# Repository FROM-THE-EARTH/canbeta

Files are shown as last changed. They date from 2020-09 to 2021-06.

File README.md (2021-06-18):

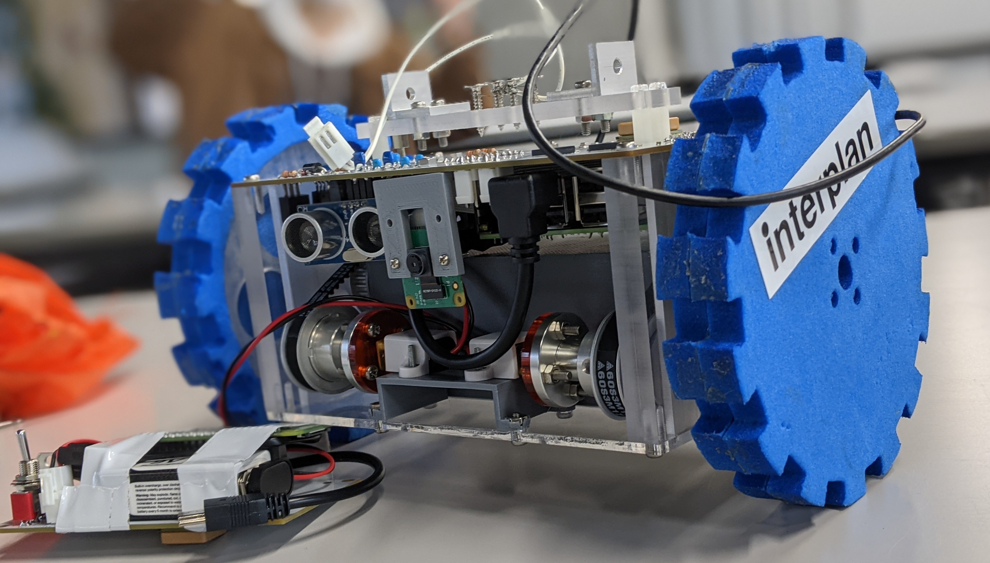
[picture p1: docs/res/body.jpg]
CanSat Beta (https://FROM-THE-EARTH.github.io/canbeta)


# canbeta

東北大学 [FTE](https://www.fte-tohoku.org/) CanSat チーム9期代のプロジェクトです．

## Dependancies

[Pipfile](./Pipfile) を参照してください．
フレームワークは [pisat](https://github.com/jjj999/pisat) を使っています．

## 開発者へ

* 必ずクローンしたら pipenv で Pipfile に沿った仮想環境を作成してください

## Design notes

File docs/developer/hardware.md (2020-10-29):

# ハードウェアとインターフェイス

## 回路図

回路図は[ドライブ](https://drive.google.com/drive/u/3/folders/1yeRXrsquoPqAf5KEmQhBFVWh2i_2MZr4)から参照可能です．
図が見づらい場合はそちらを参照してください．

### 親機

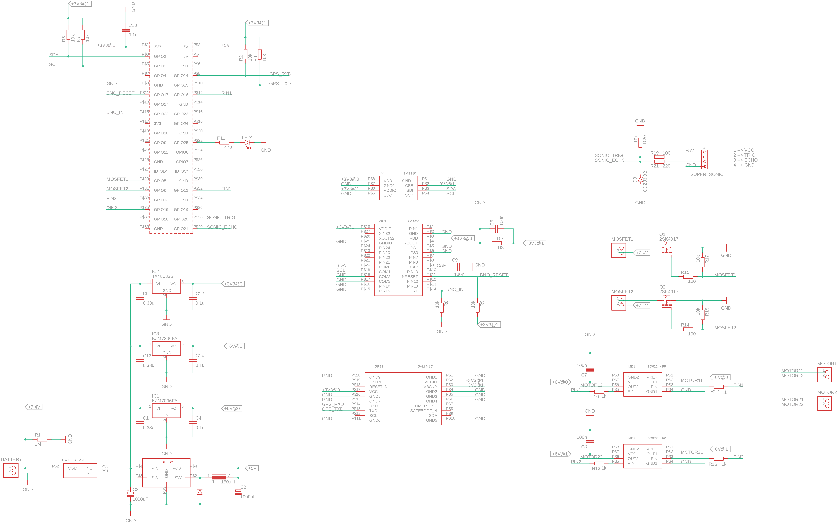
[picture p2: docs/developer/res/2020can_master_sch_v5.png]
master


### 子機

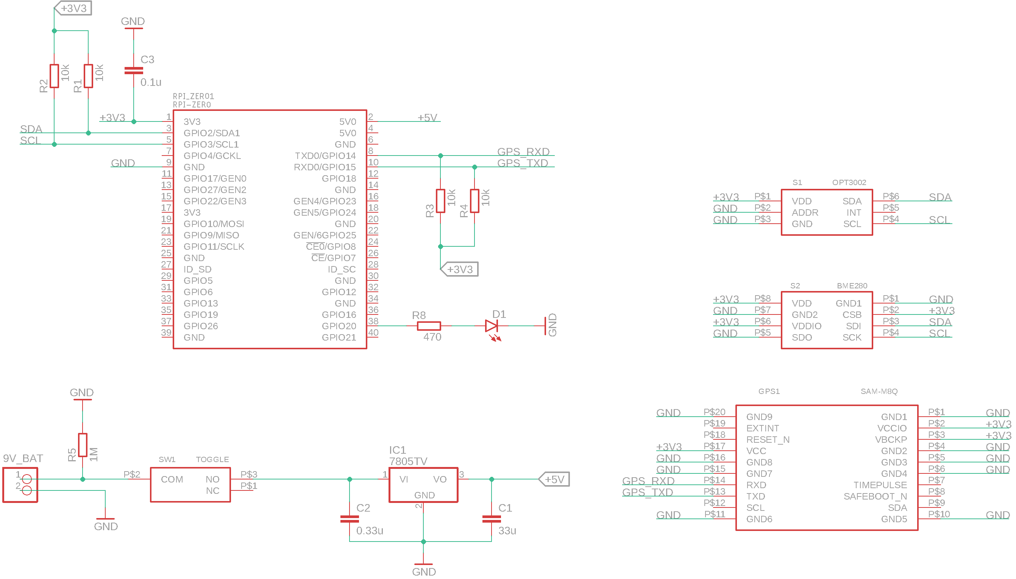
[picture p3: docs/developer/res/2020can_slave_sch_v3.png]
slave


## インターフェイス

### 親機

親機の Raspberry Pi のインターフェイスは以下のとおりです．

- I2C (BNO055, BME280)
- UART (SAM-M8Q)
- GPIO13, GPIO19, GPIO18, GPIO12 (モータドライバ)
- GPIO5, GPIO6 (電熱線用 MOSFET)
- GPIO20, GPIO21 (超音波センサ)
- GPIO17 (BNO055 リセット用)
- GPIO22 (BNO055 割り込み用)
- USB0 (IM920)

それぞれの概要については以下に示すとおりです．

#### I2C

I2C は BNO055 (9軸慣性センサ)，BME280 (気圧温湿度センサ) を利用するために用います．
I2C による信号処理のためには pisat.handler.PigpioI2CHandler を用います．
センサの利用は pisat.sensor.Bno055，pisat.sensor.Bme280 クラスを用います．
各センサの I2C アドレスは以下のとおりです．

センサ    | I2C アドレス
:--------:|:-------------:
BNO055    | 0x28
BME280    | 0x76

#### UART

UART は GPS 受信モジュールである SAM-M8Q を利用するために用います．
UART の処理には pisat.handler.PyserialSerialHandler を用います．
GPS モジュールの利用には pisat.sensor.SamM8Q クラスを用います．
使用するシリアルポートは **/dev/serial0** です．

#### GPIO13, GPIO19, GPIO18, GPIO12

これらの GPIO ピンは PWM 出力用に用います．
モータドライバは BD6222HFP です．
PWM の出力は pisat.handler.PygpioPWMHandler を用います．
2つのモータドライバは1つの二輪車として pisat.actuator.TwoWheels クラスを用いて操作します．

#### GPIO5, GPIO6

これらの GPIO ピンは MOSFET を動作させるために使用します．
pisat.handler.PigpioDigitalOutput クラスを直接用いて操作します．

MOSFET はこれらの GPIO ピンの電圧レベルを HIGH にすると動作し，電熱線に電流を流します．
つまり，テグスを焼きたいときに GPIO ピンの電圧レベルを HIGH にします．

#### GPIO20, GPIO21

これらの GPIO ピンは超音波センサを利用するために使用します．
GPIO20 は超音波センサへトリガーを送るためのデジタル出力ピンとして用います．
GPIO21 は超音波センサから返される信号を読み取るためのデジタル入力ピンとして用います．

#### GPIO17

このピンはデジタル出力として用います．
デフォルトの電圧レベルは HIGH です．
BNO055 をリセットさせる際には電圧レベルを LOW にします．

#### GPIO 22

このピンはデジタル入力として用います．
BNO055 の割り込み機能を利用する場合に用いるピンです．
割り込みが検出されると電圧レベルが HIGH になるため，これを検出することで割り込みを処理できます．

#### USB0

この USB は IM920 を利用するために使用します．
USB の使用には pisat.handler.PyserialSerialHandler を利用します．
IM920 をソケット感覚で使用したい場合は SocketTransceiver クラスでラップする必要があります．
使用するシリアルポートは **/dev/ttyUSB0** です．

### 子機

子機の Raspberry Pi のインターフェイスは以下のとおりです．

- I2C (BME280, OPT3002)
- UART (SAM-M8Q)
- USB0 (IM920)

#### I2C

I2C は BME280 (気圧温湿度センサ), OPT3002 (光センサ) を利用するために用います．
I2C による信号処理のためには pisat.handler.PigpioI2CHandler を用います．
センサの利用は pisat.sensor.Bme280, pisat.sensor.Opt3002 クラスを用います．
各センサの I2C アドレスは以下のとおりです．

センサ    | I2C アドレス
:--------:|:-------------:
BME280    | 0x76
OPT3002   | 0x68

#### UART

UART は GPS 受信モジュールである SAM-M8Q を利用するために用います．
UART の処理には pisat.handler.PyserialSerialHandler を用います．
GPS モジュールの利用には pisat.sensor.SamM8Q クラスを用います．
使用するシリアルポートは **/dev/serial0** です．

#### USB0

この USB は IM920 を利用するために使用します．
USB の使用には pisat.handler.PyserialSerialHandler を利用します．
IM920 をソケット感覚で使用したい場合は SocketTransceiver クラスでラップする必要があります．
使用するシリアルポートは **/dev/ttyUSB0** です．

## 開発の際に

開発の際にはハードウェアを利用する Node も多くあるかと思います．

まずセンサですが，**センサを明示的に利用することは避けてください**．
ただし，センサの設定を変えたい場合は別です．
そのような場合は，Node.enter コールバックで行ってください．
なぜなら，Node.judge ではセンサは常に Main スレッドに拘束されているからです．

一方，モータや通信機は特定のスレッドに拘束されていませんので，基本的には自由に使うことが出来ます．
特に Node.control 内で利用するのが良いです．

ハードウェアの部品変更があり，pisat のコンポーネントが追いついていないものがありますが，
それぞれの**基底クラス (Base の名前がついているクラス) は既に完成済み**です．
実際に使うことになる具象クラスは基底クラスのメソッドを持っているので，
具象クラスが完成していなくてもコード自体は書けます (具象クラスの実装を行うのは pisat 管理者の役目です)．

## 部品ークラス対応表

9/30 時点での部品とクラスの対応表は以下のとおりです．

| 部品名    | 具象クラス | 基底クラス                  | 具象クラスの実装状態
:----------:|:----------:|:---------------------------:|:----------------------------:
BNO055      | Bno055     | SensorBase                  | 未
BME280      | Bme280     | SensorBase                  | 済
OPT3002     | Opt3002    | SensorBase                  | 未
SAM-M8Q     | SamM8Q     | SensorBase                  | 未
*BD6222HFP  | BD62xx     | SimplePWMDCMotorDriver      | 済
IM920       | Im920      | TransceiverBase             | 済

(*注) BD62xx クラスは単体で使用せず，TwoWheels クラスを利用してください．
ただし，TwoWheels クラス生成の際に BD62xx オブジェクトが2つ必要になります．

## まとめ

ここではソフトウェア開発に必要な最低限のハードウェアの内容を説明しました．
ソフトウェアはハードウェアの抽象化の上に構築されるので，特に内部の実装に気を配る必要はありません．
ただし，抽象化されたクラスの使い方には習熟しておく必要があります．
その使い方は具象クラスの docstring などを読めばわかります．
もし，具象クラスが未実装の場合はその基底クラスを見れば大体の使い方を知ることが出来ます．

[次のドキュメント](./test.md)ではテスト方法について説明します．

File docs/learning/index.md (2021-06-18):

# 概要

ここでは後世の CanSat チームの後輩たちのための有益な情報（特に電装開発についての情報）をまとめています．ドキュメントは随時更新予定です．

## 何から始めるの？

CanSat の開発をまだ行ったことのない人にとっては，このドキュメントをどのように読み進めて良いかすらあまりわからないかもしれません．最終的に CanSat 開発を行うには，このドキュメントで述べる内容を網羅的に把握しておく必要がありますが，かといってこれらを順番に読み進めるのは退屈でつまらないことかもしれません．ここでは，読者の性質別におすすめコンテンツを紹介します．

### 完全初学者の方の場合

CanSat 開発の右も左もわからない完全初学者の方は，まず[ソフトウェア一般](software/index.md)や [Python](python/index.md) のドキュメントを読んでみるのをおすすめします．なぜなら，そもそもソフトウェアに馴染みのない状態では，実際のプログラミングや Raspberry Pi の話題にはついていけないからです．まずは，ソフトウェアの基本的な事項やプログラミング言語について学習して，ソフトウェアをもっと身近なものにすると，より発展的な議論に対する理解が進むことでしょう．

### プログラミングに自信がある方の場合

ある程度ソフトウェアやプログラミングの知識があるという方は，[ロボットプログラミング](robot/index.md)や [Raspberry Pi](raspi/index.md) などのトピックに触れてみるといいかもしれません．これらは特有のドメインを持っていて，そのドメインをよく知る人たちは（おそらく）あまり多くありません．このドキュメントはこれらの学習への良い道標になるでしょう．

### PM や AM の方の場合

PM や AM は以下のコンテンツ全般についてある程度知っておく必要がありますが，その中でも[チーム開発](team/index.md)を重点的に学習すると良いでしょう．PM や AM の役目は開発のマネージメントなので，チーム開発をどのように行えば良いかについて，他のメンバーより深く知っておく必要があります．

!!! Tip
    PM や AM が凄腕プログラマーである必要性は全くありません．PM や AM の役目はあくまでマネージメントなので，チームメンバーの責任が当分配されるように工夫するといいかもしれません．

## コンテンツ

### [ソフトウェア一般](software/index.md)

### [チーム開発](team/index.md)

### [Python](python/index.md)

### [ロボットプログラミング](robot/index.md)

### [回路設計](circuit/index.md)

### [Raspberry Pi](raspi/index.md)

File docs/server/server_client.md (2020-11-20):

# サーバーとクライアントの扱いについて

## サーバーの起動

サーバーを起動するためには，[CommandServer](../../can09/server/command_server.py) クラスを利用します．

### サーバーの初期化

*CommandServer* を初期化するためには *SocketTransceiver* オブジェクトと *Request* クラスが必要です．

*SocketTransceiver* オブジェクトは [pisat](https://github.com/jjj999/pisat/) で定義されています．
このオブジェクトは

```python
# TransceiverBase を継承したクラスのオブジェクトを作る
im920_server_handler = PyserialSerialHandler("/dev/tty/USB0")
im920_server = Im920(im920_server_handler)

# TrasnceiverBase を継承したクラスのオブジェクトをラップする
socket_transceiver_server = SocketTransceiver(im920_server)
```

のように作成します．
この SocketTransceiver オブジェクトは通信のハードウェアを定義するために必要です．

次に *Request* クラスを準備する必要があります．
これは，既に用意されているのでインポートするだけで OK です．

```python
from can09.server import Request
```

このオブジェクトはクライアントからのリクエストを処理するために必要です．
*Request* はユーティリティクラスなのでインスタンス化する必要はありません．

これらを踏まえてサーバーの初期化は

```python
from can09.server import CommandServer

server = CommandServer(socket_transceiver_server, Request)
```

で行えることが出来る．

### コマンドの登録

サーバーを初期化したら，起動する前にまずコマンドを登録する必要があります (コマンドの詳細は[こちら](./command.md))．
コマンドの登録は *append* メソッドを使って行います．
*append* は任意個のコマンドを受け付けます．

```python
# TestCommand1, TestCommand2 というコマンドがあるとします
server.append(TestCommand1, TestCommand2)
```

コマンドが比較的多い場合，

```python
commands = (TestCommand1, TestCommand2, TestCommand3, TestCommand4)
server.append(*command)
```

のように登録すると便利です．

### サーバーの起動

コマンドが登録できたらサーバーを起動できます．
サーバーは *start_serve* メソッドを利用して起動できます．
もしコマンドが1つも登録されていない場合には *RequestCommandError* を送出します．

```python
server.start_serve()
```

サーバーを起動する際はタイムアウトを設定できます．
単位は秒です．
タイムアウトは**クライアントからの1回のリクエスト受付の最大の待機時間**です．
決して，タイムアウトに設定した時間が経過すると終了するというわけではありません．

例えばタイムアウトを5秒に設定すると，5秒間リクエストがなければサーバーは終了します．
しかし，クライアントから3秒間隔でリクエストが来るような場合ではサーバーは起動し続けます．

```python
# タイムアウトを5秒に設定する場合
server.start_serve(timeout=5.)
```

## リクエストの送り方

これまでサーバー側の説明をメインに行ってきましたが，もちろんクライアント側にも所定の手順が存在します．

### サーバーへのソケットを作成する

サーバーとの通信において，クライアントを表現する特別なクラスはありません (必要ないからです)．
なので，pisat の TransceiverBase を継承したクラスのような通信機能を持つクラスならなんでも使えることになりますが，*SocketTransceiver* を利用して *CommSocket* オブジェクトを作成し通信するのが便利です．

*SocketTransceiver* のセットアップ方法はサーバーの説明で示した方法と全く同じです．

```python
from pisat.handler import PyserialSerialHandler
from pisat.comm.transceiver import Im920, SocketTransceiver

# TransceiverBase を継承したクラスのオブジェクトを作る
im920_client_handler = PyserialSerialHandler("/dev/tty/USB1")
im920_client = Im920(im920_client_handler)

# TrasnceiverBase を継承したクラスのオブジェクトをラップする
socket_transceiver_client = SocketTransceiver(im920_client)
```

次に，*CommSocket* オブジェクトを *SocketTransceiver.create_socket* メソッドを使って作成します．

```python
# アドレスの表記方法は Transceiver クラスによって異なります
# Im920 の場合はデバイスの ID のみで識別します
server_address = (3B6D,)

# 相手側のアドレスを指定してソケットを作成します
socket = socket_transceiver_client.create_socket(server_address)
```

このようにソケットを作成する利点は以下のとおりです．

- 相手側のアドレスは作成時に一回だけ指定すれば良い
- 相手が複数存在する場合にオブジェクトで区別出来る
- 他の相手とのデータの送受信の影響を受けない
- パケット量 (一度の通信でのバイト数の制限) を気にしなく良くなる

上記の利点はクライアントサーバーモデルを実装する上で重要です．
特にパケット量を気にする必要がないのは非常に強力で，多様なリクエストを可能にします．
例えば，CommSocket を用いず Im920 クラスをそのまま使った場合，リクエストが 64 byte を超過するとエラーが発生してしまいます．
つまり，リクエストは 64 byte 以下でなければならないという制限が課せられることになります．
しかし，この問題は CommSocket を利用することで回避できます．
このような理由から，クライアントが CommSocket を利用することはデファクトスタンダードであると言えます．

### ソケットでリクエストを送る

リクエストの送り方は [コマンドの説明](./command.md) で述べたレスポンスの送り方とほとんど同じです (ここではレスポンスも一種のリクエストとして実装されているからです)．
すなわち，

1. RequestForm を使ってフォームを生成
2. フォームに記入 (フォームの内容を埋める)
3. Request.make_request を使ってフォームの内容からフォーマット済みデータを作成
4. フォーマット済みデータを送信

の手順を踏みます．
最後の送信はもちろん CommSocket を利用します．

例として，以下のようなコマンドが定義されているとします ([コマンドの説明](./command.md)で使用したコマンドクラスです)．

```python
from pisat.comm.transceiver import CommSocket

from can09.server import CommandBase, ResponseBase
from can09.server import RequestForm, RequestParams, Request

class CatCommand(CommandBase):
    COMMAND = b"BB"
    LEN_ARGS = CommandParams.ARGS_ARBITARY

    @classmethod
    def exec(cls, socket: CommSocket, params: RequestParams) -> None:
        # 引数を結合する
        data_concatenated = b"".join(params.args)

        # 以下はレスポンスの作成

        # フォームを作成
        form = RequestForm()
        form.reception_num = params.reception_num
        form.command = ResponseBase
        form.args = (data_concatenated,)

        # フォームからデータを生成
        data_sending = Request.make_request(socket, form)

        # フォーマット済みデータを送信
        socket.send(data_sending)
```

このコマンドをリクエストとしてフォーマットしてサーバーに送るためには以下のようにします．

```python
import codecs

from pisat.comm.transceiver import Im920

from can09.server import CommandBase, ResponseBase
from can09.server import RequestForm, RequestParams, Request

# ソケット作成部分は省略

args = ["Hello", "World", "!!!"]
args = tuple(map(Im920.encode, args))

# RequestForm オブジェクトを作成
form = RequestForm()

# フォームに必要な内容を登録
form.reception_num = 100
form.command = CatCommand
form.args = args

# フォーマット済みデータを生成
data_sending = Request.make_request(socket.addr_yours, form)

# IM920 はASCII文字の16進数表現なので追加で変換
data_sending = codec.encode(data_sending, "hex_codec")

# データ送信
socket.send(data_sending)
```

### レスポンスを確認する

リクエストを送るとコマンドによってはサーバーはレスポンスを返します．
さきほど例として作った CatCommand もレスポンスを返すコマンドです．
レスポンスを見るためには *Request* クラスの *parse_request* メソッドを使います．
このメソッドを使用すると，リクエストが解析され *RequestParam* というクラスが返ってきます．
この *RequestParams* クラスにはレスポンスとして送られきた内容が全て含まれています．

```python
# レスポンスを解析する．CommSocket オブジェクトを渡すことで
# 勝手に必要なだけデータを受信し解析を行うので，このメソッド
# を呼び出す前に socket.recv などでデータを受信する必要はあり
# ません (というかデータが壊れるのでやらないでください)．
params = Request.parse_request(socket)
```

*RequestParams* には以下のような属性があります．

- *reception_num* (リクエストを送る際に設定した数字)
- *command* (レスポンスなので **FF** で固定)
- *address* (サーバーのアドレス)
- *args* (レスポンス内容)

それぞれ[フォーマットの説明](./format.md)で述べたパラメータに対応しています．
最も重要な属性は *RequestParams.args*  という属性です．
この属性にはレスポンスの内容がタプルとして格納されています．
例えば上の例だと，CatCommand というコマンドはクライアントから受け取った引数を結合し，レスポンスとして返すコマンドであったので，

```python
# 内容は bytes で格納されているのでデコードして str にしておく
args = list(map(Im920.decode, params.args))

print(args)
# [HelloWorld!!!]
```

のように返ってくるはずです．
このようにしてサーバーがリクエストに対して返したレスポンスを確認することが出来ます．

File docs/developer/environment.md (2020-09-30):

# 環境構築

## Python

まずは PC 内で開発を行うための環境構築を行ってください．
開発で使用するのは **Python 3.7** です．
もし，Python 3.7 以外のバージョンしかインストールされていない場合は
pyenv などを利用し Python 3.7 を使用できる環境を整えてください．
別のバージョンが存在したとしても，特に削除する必要はありません．

### pyenv 

以下のサイトを参考に pyenv をインストールし，Python のバージョン管理を出来るようにしてください．

- [Windows](https://obataka.com/create-windows-python-virtualenv/)
- [Mac](https://qiita.com/koooooo/items/b21d87ffe2b56d0c589b)
- [Linux](https://qiita.com/neruoneru/items/1107bcdca7fa43de673d)

### pipenv

pipenv は Python の仮想環境を構築し，外部ライブラリの依存関係をその中に整理するために使用するツールです．
インストールは

```
$ pip install pipenv
```

で出来ます ($ はコマンドを示すための単なる記号で入力しなくていいです)．
pipenv がインストール出来たら，clone してある fte-can09 リポジトリのルート(ディレクトリの最上部) で

```
$ pipenv install
```

をすると仮想環境を構築し，fte-can09/Pipenv に定義してある外部ライブラリをインストール出来ます．
**Pipfile** はそのプロジェクトの環境の全てが記載されているファイルです．
Pipfile さえあれば，pipenv を用いていつでも容易に環境構築が可能です．

その他の pipenv の使用方法は[こちら](https://qiita.com/y-tsutsu/items/54c10e0b2c6b565c887a)を参照してください．

### VS Code の設定

エディタは VS Code を利用することを推奨しています．
拡張機能についての制限は特に行っていません．

VS Code では構文解析を行う Python インタープリタを指定することが出来ます．
今回は pipenv で仮想環境を構築したので，その環境でのインタープリタを使用します．
まず，Python スクリプトを開いている状態で，VS Code の画面下の青いバーの左側にある Python... という項目をクリックします．
その後，画面上部中央に利用可能な Python インタプリタがリストされると思いますが，
そこで fte-can09 の名前を含むものを選択します．
すると，編集している Python スクリプトがその仮想環境内で使用している外部ライブラリなどをもとに解析されるので，
インポートエラーのような表示が出なくなります．

### 環境構築における注意点

- pipenv で勝手に他の外部ライブラリをインストールしないでください
- 外部ライブラリが必要になるようであれば，MTG で相談してください
- わからないことがあったら積極的に聞いてください

## Raspberry Pi

### SD

Raspberry Pi 用の SD カードの作成は [Raspberry Pi Imager](https://www.raspberrypi.org/downloads/) を使用すると楽です．
OS は Raspberry Pi OS を選択してください．

### Python

Raspberry Pi における Python の環境構築は PC での環境構築方法と同一です．
pipenv は環境構築のために使うので必ずインストールしておいてください．
VS Code は今のところ公式でサポートされていないのでインストールしなくても大丈夫です．

Raspberry Pi をインストールしたての状態では，ターミナル上で

```
$ python
```

と打つと Python 2系が起動されます．Python 3系を起動するためには

```
$ python3
```

と打つ必要があります．
面倒な場合はエイリアスを作成する方法があります．

### Git

Git はデフォルトでインストールされていないかもしれないのでインストールしておきましょう．
ターミナルで，

```
$ sudo apt install git
```

と打てばインストール出来ます．
ユーザー名と E-mail アドレスの設定なども行っておきましょう．

Git のセットアップが出来たら，このリポジトリをクローンしてください．

```
$ git clone https://github.com/jjj999/fte-can09.git
```

クローンし終わったらそのリポジトリのルートに移動し，Python の環境構築を行うために

```
$ pipenv install
```

をします．
これで PC と Raspberry Pi の Python に関する環境が同期されます．

## まとめ

今回のプロジェクトで環境構築が必要なデバイスは

- PC
- Raspberry Pi

の2つです．
また，それぞれの環境を出来るだけ近いものにするために **pipenv** を用います．
環境構築は面倒ですが，一度理解してしまえば単純作業です．

環境構築のためのツールとして，今回のプロジェクトでは

- pyenv
- pipenv
- Git

を利用します．
重要な点は Pipfile さえあれば pipenv で Python の環境構築がほぼ終わるということです．

[次のドキュメント](./development.md)では開発の流れについて説明します．

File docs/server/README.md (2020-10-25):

# サーバー機能について

## 概要

サーバー機能は文字通り機体にサーバーとしての振る舞いをさせるための機能です．
サーバー機能に関するコードは [can09/server/](../../can09/server/) にあります．

そもそもサーバーとは，コンピュータネットワークモデルの1つである[クライアントサーバーモデル](https://ja.wikipedia.org/wiki/%E3%82%AF%E3%83%A9%E3%82%A4%E3%82%A2%E3%83%B3%E3%83%88%E3%82%B5%E3%83%BC%E3%83%90%E3%83%A2%E3%83%87%E3%83%AB)におけるサーバーのことです．
クライアントサーバーモデルにはクライアントとサーバーという2つの登場人物が出てきて，クライアントがサーバーに何らかの処理を**リクエスト**し，サーバーがそのリクエストに対して**レスポンス**を返すという方式をとります．
つまり，クライアントとサーバーには明確な主従関係があることになります．

今回のミッションでクライアントサーバーモデルを採用する理由は，親機は基本的にアクティブであるのに対し，子機はアクチュエータを持たず，ミッション中の単体の役割が曖昧である点にあります．
そこで，**子機をサーバー化**してしまい，親機をクライアントとすることで，子機のミッション中における役割を明確化することにしました．

本ミッションではクライアントは親機および管制局なので，クライアントサーバーモデルを採用する大きな恩恵は受けられませんが，このモデルは複数の機体をいっぺんに走査させる場合には大きな価値を持ちます．
つまり，クライアントが惑星探査を行いながら，データの整合性やミッションの進捗などをサーバーが管理するわけです．
残念ながら今回のミッションではそのような大規模なことは行えませんが，今後の開発の指針となるような試みであるとは言えるでしょう．

## フォーマット

クライアントがサーバーにリクエストを送るにも，サーバーがクライアントにレスポンスを送るにも，どちらもある決まったデータのフォーマットを必要とします．
もし所定のフォーマットでデータが送られてこなければ，コンピュータはデータを認識することが困難になるためです．

フォーマットは[こちら](./format.md)で定義されています．
フォーマットの詳細を把握する必要はありませんが，通信関連の処理を行う場合にはざっくりと把握しておくと良いでしょう．

## コマンド

リクエストの中身は主に**コマンド**とその**引数**で出来ています．
これは，ターミナルで打つコマンドの内容を通信でやり取りしているというイメージです．

コマンドは [CommandBase](../../can09/server/command_base.py) を継承するクラスで表現されます．
コマンドクラスの詳細については[こちら](./command.md)を参照してください．

## サーバーとクライアント

フォーマットやコマンドはただの情報を表す概念に過ぎません．
実際にフォーマットやコマンドを使って通信を行うのはサーバーとクライアントです．

サーバーは [CommandServer](../../can09/server/command_server.py) を利用します．
このクラスはサーバーを起動するとクライアントからのリクエストを受け付け，リクエストが来るとその内容 (主にコマンドと引数) を解析し，その内容に基づいて処理を行い，必要があればクライアントにレスポンスを返します．

クライアントにはクライアント用の特別なクラスは用意されていませんが，pisat.comm.transceiver.CommSocket を利用すると便利です．
このクラスは自分のアドレスと相手のアドレスをつなぎ，まるでその間だけの通信であるかのように偽装します．
つまりクライアントは CommSocket をサーバーのアドレスを指定して生成することで，サーバーとのコネクションを獲得するわけです．

サーバーとクライアントの詳細については[こちら](./server_client.md)を参照してください．

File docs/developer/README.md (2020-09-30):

# 開発ドキュメント

本プロジェクトの開発者用ドキュメントです．

## 目次

1. [環境構築](./environment.md)
2. [開発の流れ](./development.md)
3. [ハードウェアとインターフェイス](./hardware.md)
4. [テストと依存関係の解決](./test.md)

## 参考文献

### Python 一般

- [チュートリアル](https://docs.python.org/ja/3/tutorial/index.html)
- [標準ライブラリ](https://docs.python.org/ja/3/library/index.html#library-index)
- [言語リファレンス](https://docs.python.org/ja/3/reference/index.html)

### よく使うと思われる Python ライブラリ

- [組み込み関数](https://docs.python.org/ja/3.6/library/functions.html)
- [組み込み型](https://docs.python.org/ja/3.6/library/stdtypes.html)
- [コンテナデータ型 collections](https://docs.python.org/ja/3.6/library/collections.html)
- [列挙型 enum](https://docs.python.org/ja/3.6/library/enum.html)
- [数学関数 math](https://docs.python.org/ja/3.6/library/math.html)
- [csv](https://docs.python.org/ja/3.6/library/csv.html)
- [json](https://docs.python.org/ja/3.6/library/json.html)
- [スレッド threading](https://docs.python.org/ja/3.6/library/threading.html)
- [並列タスク実行 concurrent.futures](https://docs.python.org/ja/3.6/library/concurrent.futures.html)
- [テストフレームワーク](https://docs.python.org/ja/3.6/library/unittest.html)

### よく使うと思われる Python 外部ライブラリ

- [pigpio](http://abyz.me.uk/rpi/pigpio/python.html)
- [picamera](https://picamera.readthedocs.io/en/release-1.13/)
- [Numpy](https://numpy.org/doc/stable/)
- [Matplotlib](https://matplotlib.org/contents.html)
- [OpenCV](https://docs.opencv.org/master/d6/d00/tutorial_py_root.html)

### pyenv

- [Windows](https://obataka.com/create-windows-python-virtualenv/)
- [Mac](https://qiita.com/koooooo/items/b21d87ffe2b56d0c589b)
- [Linux](https://qiita.com/neruoneru/items/1107bcdca7fa43de673d)

### pipenv

- [入門](https://qiita.com/y-tsutsu/items/54c10e0b2c6b565c887a)
- [基礎](https://pipenv-ja.readthedocs.io/ja/translate-ja/basics.html)
- [応用](https://pipenv-ja.readthedocs.io/ja/translate-ja/advanced.html)

### Git

- [Git book](https://git-scm.com/book/ja/v2/)
- [基礎](https://tracpath.com/bootcamp/learning_git_firststep.html)

### Markdown

- [チートシート](https://gist.github.com/mignonstyle/083c9e1651d7734f84c99b8cf49d57fa)

### Raspberry Pi セットアップ

- [Raspberry Pi Imager](https://www.raspberrypi.org/downloads/)

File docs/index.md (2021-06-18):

CanSat Beta (https://FROM-THE-EARTH.github.io/canbeta)

# canbeta

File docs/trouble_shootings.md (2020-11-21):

# トラブルシューティング

## BNO055 の出力がずっと0になる

動作モードが config モードのままかもしれません．

```python
bno055.change_operation_mode(Bno055.OperationMode.NDOF)
```

を実行してみてください．

## シリアル通信が出来ない

デバイスファイルを読み書きする権限が付与されていない可能性があります．以下のコマンドを実行してみてください．

```
$ sudo chmod 777 (デバイス名)
```

## SAM-M8Q のデータが取れない

以下のコマンドを打ってみてください．

```
$ stty -F /dev/(デバイス名) -echo
```

デバイス名は基本は serial0 です．

## IM920 が動作しない (1)

ボーレートが合っていない可能性があります．IM920 のボーレートは19200Hzです．handler を19200Hzのボーレートで初期化して使用してください．

```python
from pisat.handler import PyserialSerialHandler
from pisat.comm.transceiver import Im920

handler = PyserialSerialHandler("/dev/ttyUSB0", boadrate=19200)
im920 = Im920(handler)
```

## IM920 が動作しない (2)

ペアリングが行われていない可能性があります．IM920 にはIDがあり，裏側に書いてある6桁の数字がIDです．相手側のIDを登録しておかないと受信を行うことが出来ません．

6桁の数字のIDの登録方法には2通りあります．1つ目の方法は数字を16進数に直して登録する方法です．

```python
# ID: 007378
# -> 16進数: 1CD2
im920.add_rec_id("1CD2")
```

2つ目の方法は6桁の数字を直接渡し，is_hex 引数を True に設定する方法です．この方法が計算しなくても出来るので簡単です．

```python
# ID: 007378
im920.add_rec_id("007378", is_hex=True)
```

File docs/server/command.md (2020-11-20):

# コマンドについて

## コマンドの定義方法

この通信におけるコマンドは通常の PC のターミナルで行うコマンドとほとんど同じ構造をしています．
つまり，コマンド名があり引数があり，その情報をもとに処理を実行します．
ただし以下の点が異なります．

- オプション引数はなく位置引数のみを持ちます
- 結果もコマンド (コマンド名はFF) として返ってくる
- コマンドは CommandBase のサブクラスとして定義される

特にコマンドの定義という点で上の3つの項目のうち最後の項目が重要になります．

コマンドの基礎となる CommandBase は非常に軽量なクラスです．
ユーザーが実質的に定義すべき項目は3つだけです:

```python
from enum import Enum, auto
from typing import Any

from pisat.comm.transceiver import CommSocket

from can09.server.request import RequestParams

class CommandParams(Enum):
    ARGS_NOTHING = auto()
    ARGS_ARBITARY = auto()

class CommandBase:
    
    COMMAND = b""
    LEN_ARGS = CommandParams.ARGS_NOTHING
    
    @classmethod
    def exec(cls, socket: CommSocket, params: RequestParams) -> Any:
        pass

class ResponseBase(CommandBase):
    
    COMMAND = b"FF"

```

*COMMAND* はコマンド名で bytes 型です．
[フォーマットの説明](./format.md)でも述べたようにコマンド名はアルファベット2文字です．

*LEN_ARGS* はコマンドの引数の数です．
特別な引数の数として CommandParams の属性を使うことも出来ますが，使わなくても OK です．

*exec* はサーバーが *COMMAND* と同じコマンド名を持つリクエストを受けた場合に呼び出されるメソッドです．
つまり，コマンドの実行は具体的にこのメソッドで行われます．
引数には *CommSocket* と *RequestParams* が渡されます．
*CommSocket* は pisat で定義されているもので，自分のアドレスと相手のアドレスをつなぎ，いかにも 2 つの端末間で通信がなされているかのように見せかけることが出来るオブジェクトです．
コマンドは *CommSocket* を使ってレスポンスを返すことが出来ます．
*RequestParams* は[フォーマットの説明](./format.md)で述べられたフォーマットの各パラメータが格納されたクラスです．
このクラスからリクエストの内容について (例えばコマンドの引数) 知ることが出来ます．

上のコードスニペットからわかるように，CommandBase にはインスタンス変数やインスタンスメソッドは一切ありません．

例として，引数を結合してクライアントにレスポンスを返すコマンドを作ってみます．

```python
from pisat.comm.transceiver import CommSocket

from can09.server import CommandBase, ResponseBase
from can09.server import RequestForm, RequestParam, Request

class CatCommand(CommandBase):
    COMMAND = b"BB"
    LEN_ARGS = CommandParams.ARGS_ARBITARY

    @classmethod
    def exec(cls, socket: CommSocket, params: RequestParams) -> None:
        # 引数を結合する
        data_concatenated = b"".join(params.args)

        # フォームを作成
        form = RequestForm()
        form.reception_num = params.reception_num
        form.command = ResponseBase.COMMAND
        form.args = (data_concatenated,)

        # フォームからデータを生成
        data_sending = Request.make_request(socket, form)

        # フォーマット済みデータを送信
        socket.send(data_sending)
```

上の例のように，レスポンスを返す手順は

1. RequestForm を使ってフォームを生成
2. フォームに記入 (フォームの内容を埋める)
3. Request.make_request を使ってフォームの内容からフォーマット済みデータを作成
4. フォーマット済みデータを送信

の流れになります．
上記の例では引数を結合するという意味のない処理をしていましたが，これを他の処理に変えることでコマンドをいくらでも多様にすることが出来ます．

## コマンドの登録

定義したコマンドはサーバーに追加してあげなければ動作しません．
サーバークラスとしては CommandServer を用いる必要があり，

```python
command_server.append(CatCommand)
```

のように，append メソッドを用いてコマンドを**クラスのまま追加**しなければなりません．

## コマンドの種類

現時点で用意されているコマンドを以下に列挙します．
アルファベット2文字はコマンド名です．

### レスポンスを返す (FF)

### プログラムを終了させる

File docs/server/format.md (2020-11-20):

# フォーマットについて

## 概要

本ミッションでは，子機は基本的にサーバーのように動作します．
もちろんネットワークはインターネットのようなものではなく IM920 による通信網であり，クライアントは親機または管制局です．

子機には IM920 を使って様々なコマンドを送れるようにします．
子機は受け取ったコマンドに応じて処理を行い，コマンドによってはレスポンスを返すことが出来ます．
一方，親機はミッション中に子機にコマンドを送り，そのレスポンスをもらいながらミッションを効果的に進めることが出来ます．

コマンドは単に送っただけでは意味がありません．
送ったコマンドは受信側で正しく解釈される必要があります．
そのためには，送信情報がコマンドを含む一定フォーマットに則っていなければなりません．
以下では，そのフォーマットを定義します．

## リクエストのフォーマット

基本的なリクエストのフォーマットは

```
$(受付番号)(コマンド名)(アドレス)$(各引数の byte 数)$(引数1)(引数2)...
```

とします．
メインのセパレータとしては **$** を使用します．

受付番号およびコマンド名は固定長なので，($ も含む) 先頭の4 byte をヘッド (head) と呼ぶことにします．

### 受付番号 (固定長 1 byte)

受付番号は1 byte (8 bit) からなります．
受付番号はクライアント側が設定できる任意の番号です．
サーバーはクライアントからリクエストを受け，その処理を実行し，レスポンスにクライアントから受け取った受付番号をそのまま添付して返します．
そして，それを受け取ったクライアントはその受付番号からどのリクエストに対するレスポンスかを判断することが出来ます．

レスポンスの速い通常のサーバーに受付番号などというものはいりませんが，子機はサーバーとしての性能は優れていないため，レイテンシの問題に対処するために受付番号を導入しました．

### コマンド名 (固定長 2 byte)

コマンド名は英数字2文字とします．
つまり，使える文字は 0 ~ 9, a ~ z, A ~ Z であり，3844通りのコマンドを設定できます．

### アドレス (任意長)

アドレスは pisat.comm.transceiver.TransceiverBase を継承したオブジェクトの送信側のアドレスです．
Transceiver オブジェクトのアドレスは一般にタプルで表現されますが，(arg1, arg2, ..., argN) で表現されるアドレスは

```
arg1:arg2:...:argN
```

とセミコロンで区切って表現します．

### 各引数の byte 数 (任意長)

byte 数は16進数で表現します．
その長さに制限はありません．
複数の引数がある場合，

```
(引数1の byte 数):(引数2の byte 数):...:(引数Nの byte 数)
```

と表現します．

これは任意のバイトを含む引数を処理するために必要な情報です．

### 引数 (任意長)

引数には特に制限はありません．
一般に引数は複数存在しますが，各引数はセパレータなしにそのまま結合されます．

## レスポンスのフォーマット

レスポンスのフォーマットはリクエストとほぼ同じです．
ただし以下の点が異なります．

- コマンドが **FF** で固定
- 引数の代わりに結果が返ってくる

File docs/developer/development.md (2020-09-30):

# 開発の流れ

## Git

開発には Git を利用します．
知識としては [Git book](https://git-scm.com/book/ja/v2/) の2, 3章を理解しておけば十分です．
忘れたら再度確認しましょう．

## 基本的な流れ

各自でブランチを作成してそのブランチ上で開発を行ってください．
開発は自分の担当の Node を最優先に行ってください (出来る限りコンフリクトは起こしたくないです)．

開発がある程度進んだら Github の Issues でマージ要求を発行するか，プルリクエストを発行してください．
適切だと判断されれば，ブランチは master にマージされます．
マージされたブランチは削除してしまって構いません．
新たにタスクが発生したら，最新の master から再度ブランチを作成してください．

## Slack との連携

リモートリポジトリ (Github上のリポジトリ) が更新されると，Slack に自動アナウンスされるように設定されています．
つまり，Push や Issues などの操作を行うと Slack に通知が来ます．
誰がやっても通知が来るので，更新を行ったら他のメンバーに知らせるために push するようにしましょう．

## その他

### 依存ライブラリの更新

以下のコマンドで，現在依存している外部ライブラリの内容を更新できます．

```
$ pipenv update
```

### 注意点

作成したブランチで master ブランチをマージすることはやめてください．

## まとめ

今回のプロジェクトでは Git を利用して

1. 各自でブランチを持つ
2. ブランチの開発がある程度終わったら master にマージ
3. 再度ブランチを作成

の繰り返しで開発を進めていきます．
更新記録は Slack を通して他のメンバーに通知されます．
他のメンバーの更新記録は時間があるときにチェックしておくと良いでしょう．

[次のドキュメント](./hardware.md) ではハードウェアの話をします．
主にピンアサインなどの確認を行います．

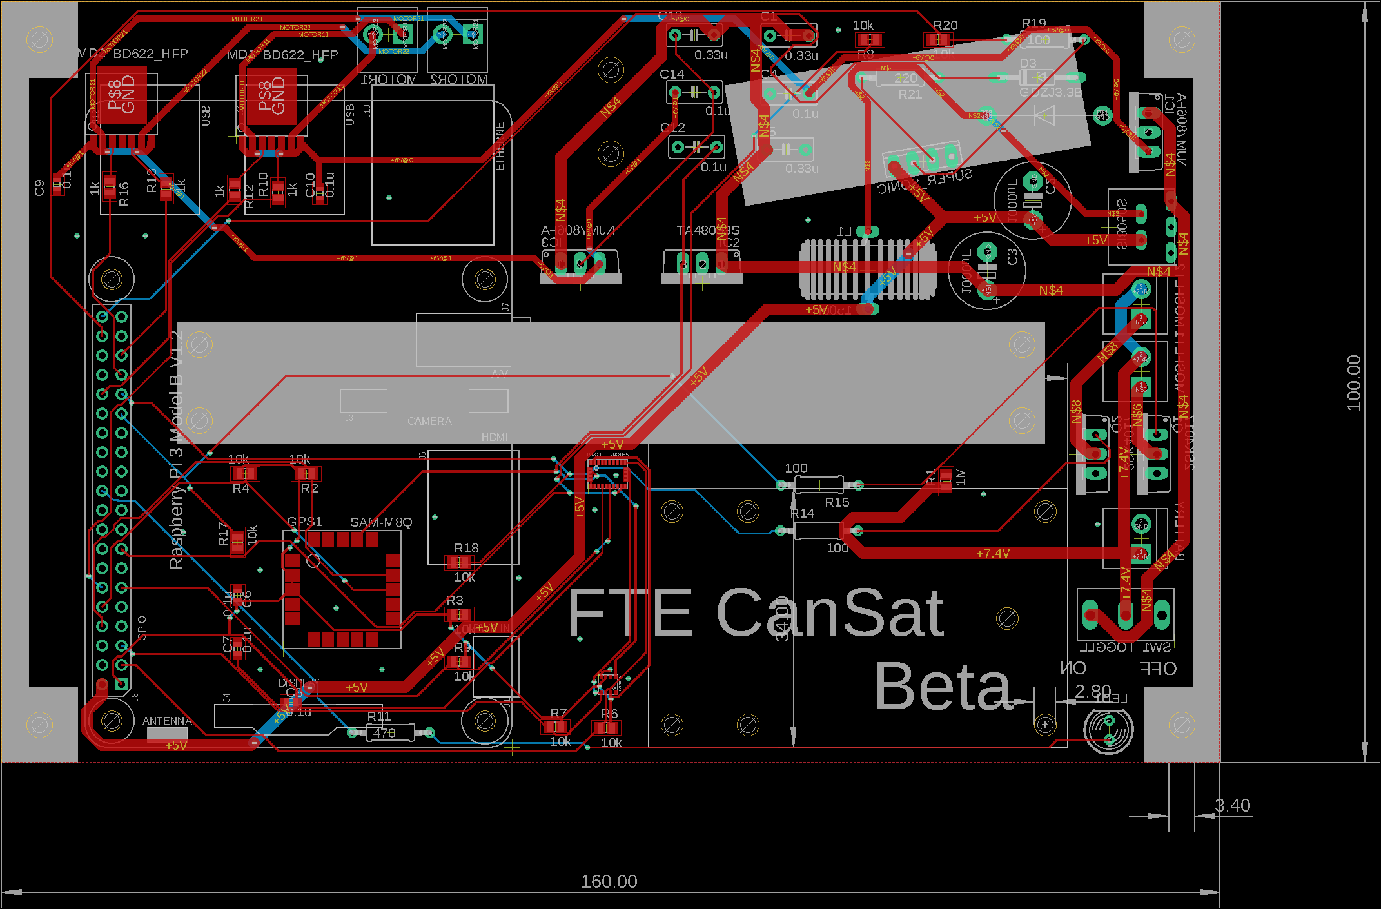
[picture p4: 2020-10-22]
circuits/images/parent_brd.png

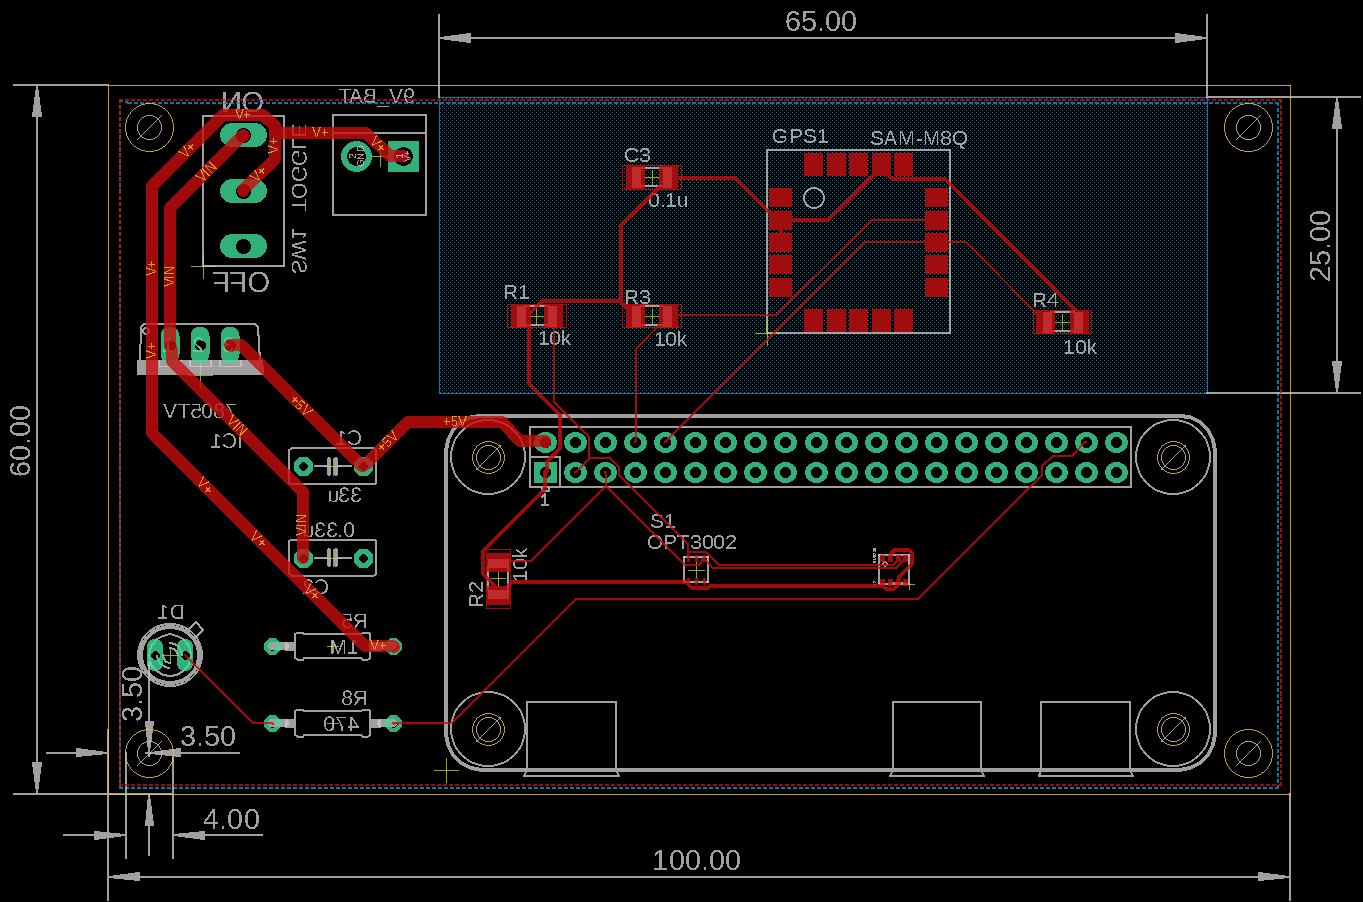
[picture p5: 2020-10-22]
circuits/images/child_brd.png

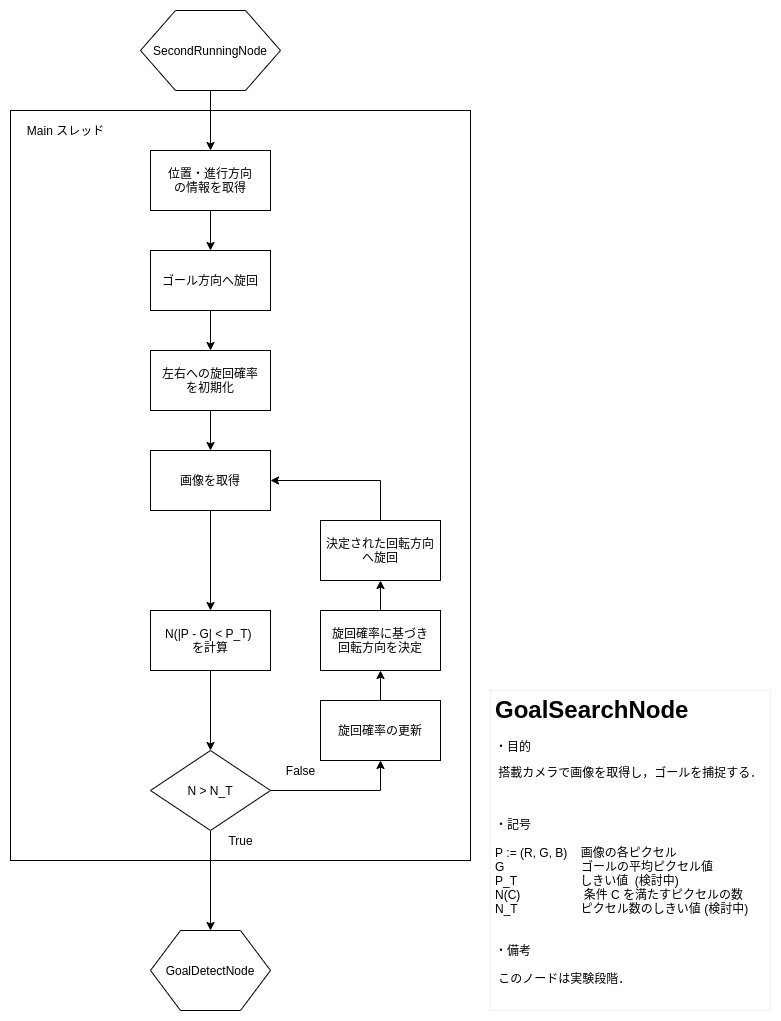
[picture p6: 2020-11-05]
docs/nodes/parent/img/goal_search_node.png

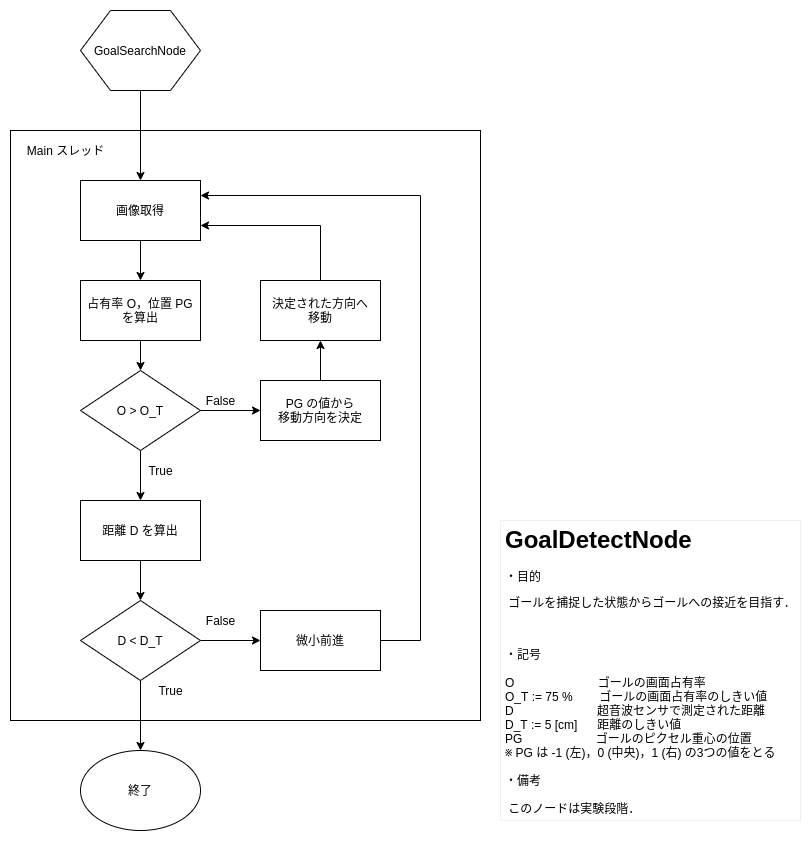
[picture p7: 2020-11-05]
docs/nodes/parent/img/goal_detect_node.png

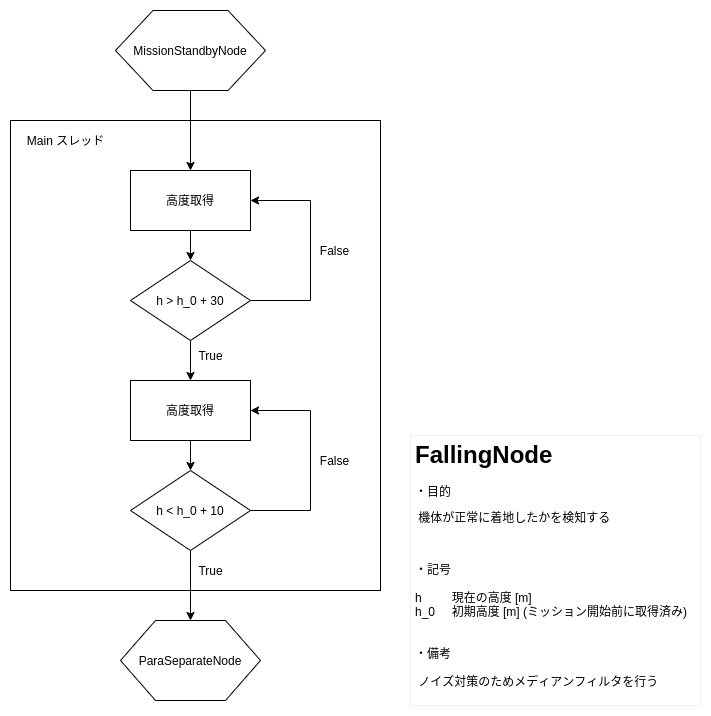
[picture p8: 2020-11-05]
docs/nodes/parent/img/falling_node.png

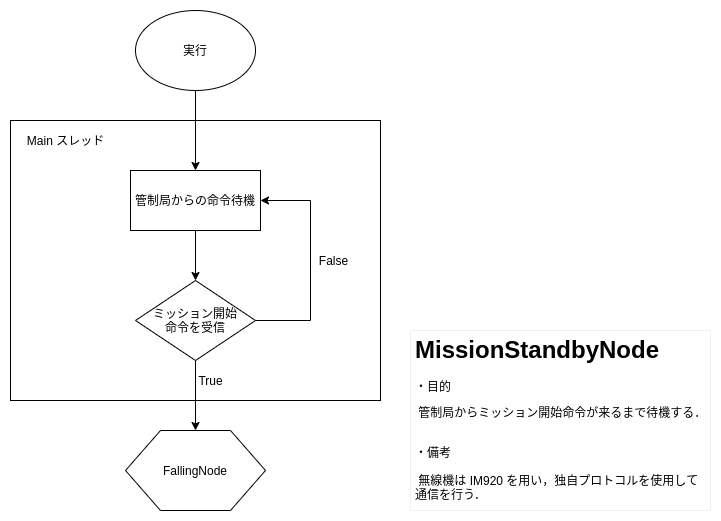
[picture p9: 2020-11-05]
docs/nodes/parent/img/mission_standby_node.png

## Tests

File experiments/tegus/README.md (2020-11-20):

# テグス熱融解試験

## 目的

パラシュートおよび子機の固定にテグスを利用し，その分離を電熱線を熱することで行う．
ここではミッションで使用するための電熱線に電圧を印加する時間を求めることを目的とする．

## 方法

電熱線に約 7.4V の電圧を印加し，テグスが融解する時間を計測する．
可能であれば複数回行う．

## 結果

テンションがかかった状態でテグスが切れるまで約 1 ~ 2 秒程度要した．

## 考察

本試験の結果から電熱線へ10秒ほど電圧を印加すればテグスは十分切れると考えられる．

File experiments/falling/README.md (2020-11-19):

# 落下検知・パラシュート分離テスト

## 目的
NSE に参加するのに伴い，参加団体には審査書の作成が求められる．
これは投下実験に参加する機体がレギュレーションに沿っているかの確認，また試験を完了できる機体であるかを事前に確認するE2E試験に分かれている．
今回は機体を用いてE2E試験を行い，またそのデータを得ることを目的とする．

## 概要

このテストでは主に MissionStandbyNode ~ ParaSeparateNode までのコンテクストについてテストする．
このテストは E2E 試験の前半部分を兼ねており，

- 管制局からのミッション開始命令をちゃんと受け取れるか
- パラシュートが適切に開くか
- パラシュート展開時の荷重がいくらか
- 着地の荷重がいくらか
- 機体が着地衝撃に対して十分な耐性があるか
- 落下時の機体の終端速度がいくらか
- パラシュート分離が適切に行われるか
- コンテクストが適切に進行するか

という点を基準に評価する．

## 方法

まず落下する地上の高度と機体を投下する地点の高度を observe_altitude.py を実行して調べ，それを記録しておく．
次に，記録した2つの高度から適切なしきい値を決定し，exp_falling.py 内で FallingNode のしきい値を決定したしきい値に上書きする．
その後，exp_falling.py を実行し，機体を投下地点に持っていき数秒間待機してから投下する．
投下後，機体を回収しデータを解析する．

### 荷重の解析

### 終端速度の解析

## 結果

- 実施日時 : 2020/11/xx
- 実施場所 : 
- 設定値
    * $h = 10$ [m]

### 開傘衝撃

### 着地衝撃

### 終端速度

## 考察

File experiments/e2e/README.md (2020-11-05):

# E2Eテスト

## 目的

作成したアプリケーションのミッション遂行能力を確かめる．

## テスト方法

### 概要

テストはコンテクストを次の2つに分けて行う．

1. MissionStandbyNode ~ ParaSeparateNode (C1)
2. FirstRunningNode ~ GoalDetectNode (C2)

2つのテストはその一部始終を動画で記録する．

### C1

C1 は[落下検知・パラシュート分離テスト](../falling/)で行った結果を利用する．

### C2

C2 は走行に関わるコンテクストである．
このテストで主に評価する部分は次の2つ:

1. 子機を定めた座標の半径$x$[m]以内に分離できるか
2. ゴール (三角コーン) へ向けて接近できているか

## 結果

### 第1実験

- 実施日時 : 2020/11/xx
- 実施場所 : 
- 設定値
    * $x = 1$
    * 子機放出座標 (latitude, longitude)
    * ゴール座標 (latitude, longitude)

## 考察

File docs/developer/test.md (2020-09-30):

# テストと依存関係の解決

## テストの概要

### テストスクリプト

テストスクリプト (テスト用の Python ファイル) は fte-can09/test/ ディレクトリ内に置いてください．
そして必ず **test_xxxxxxx.py** という命名規則でファイル名を作成してください．
xxxxxx の部分はテストするクラス名やファイル名にするとわかりやすいです．

テストスクリプトはテストしたい内容を自由に記述してください．
本来は [unittest](https://docs.python.org/ja/3.6/library/unittest.html) というテストフレームワークを
使用するべきですが，習得コストがかかるので現在は検討中です．

### 環境

PC 環境で出来るテストのほとんどが**論理テスト**です．
つまり，論理的に上手くいくかどうかのテストしか行うことが出来ません．
それもセンサやモータなどの外部機器を一切使わずにです．
ただし，PC に接続可能な機器については実機テストを一部行うことが出来ます．

基板は現在発注手続きを進めていますが，早ければ10月の中旬，遅ければ10月末あたりに完成する予定です．
つまり，11月に実機テストラッシュを行うことになるため，10月中は論理テストのみの実行で開発を進めてください．

実機がないことへの対応として，Precursor の実機を使用してみようと考えています．

## 依存関係の解決

テストスクリプトを書く際に，import エラーにハマる可能性があります．
import エラーが発生する原因は，can09 パッケージが仮想環境における Python インタプリタの参照先ディレクトリ内
に含まれていないからです．
Python インタプリタの参照先リストは

```python
import sys

print(sys.path)
```

とすると参照出来ます．
ちなみに sys.path は参照先ディレクトリのリストです．

この問題を解決するには2つの方法があります．

1. 参照ディレクトリ内に can09 のコピーを人為的に加える
2. sys.path に can09 の親ディレクトリを append する

### 参照ディレクトリ内に can09 のコピーを人為的に加える

この方法をとるためには fte-can09/local.py というファイルを使います．
Windows の場合と Mac，Linux の場合で方法が異なります．

この方法は仮想環境内に can09 を取り込ませるので，VS Code の構文解析もでき非常に便利です．
ただし，can09 が更新される度にコピーを実行する必要があります．
なぜなら，コピーした内容はその当時の内容のままだからです．

#### Windows の場合

リポジトリのルート (fte-can09 上) で **local.py** ファイルを実行します．

```
$ python local.py
```

すると，仮想環境内の参照先ディレクトリにそのときの can09 パッケージのコピーが追加されます．

#### Mac, Linux の場合

この場合，ひと手間加える必要があります．
まず，**local.py をコピー**します．
名前は **_local.py** にしておいてください (.gitignore に登録済みなので)．

```
$ cp local.py _local.py
```

そして，_local.py の印がある場所に変更を加えます．
変更する変数は **name_env** です．
これは仮想環境の名前で **fte-can09-xxxxxxxxxxxx** という名前です．
仮想環境の名前は

```
$ ls ~/.local/share/virtualenvs/
```

とすると見つけることが出来ます．
仮想環境の名前を見つけたらコピーし，*name_env* 変数に設定します．

```python
...

if __name__ == "__main__":
    name_pkg = "can09"
    name_env = "fte-can09-xxxxxxx"             # TODO add env name if in Mac or Linux
    version_python = "3.7"

    main(name_pkg, name_env)
```

そして _local.py を保存し実行します．

```
$ python _local.py
```

すると，仮想環境内の参照先ディレクトリにそのときの can09 パッケージのコピーが追加されます．

### sys.path に can09 の親ディレクトリを append する

この方法は Python 実行時に can09 をインポート出来るように設定する方法です．
can09 の親ディレクトリである fte-can09 を sys.path に append すればOKです．

```python
import sys
import os

# can09 をインポートする前に append
sys.append(os.path.abspath(".."))     # fte-can09/test にいる場合
import can09
```

この方法を利用すると特別になにかしなくても最新の can09 をインポート出来ます．
したがって上のようなコードを覚えれば便利だと思われるかもしれませんが，
次のようないくつかの欠点もあります．

- fte-can09 の場所がメンバー全員一緒とは限らない
- ファイルを書く度に必要
- VS Code による can09 パッケージの構文解析が行われない

特に1番目と3番目が開発において致命的です．
したがって，can09 のインポートエラーを解決するためには，基本的に **local.py を実行する方法** を利用してください．

## Node.judge のシミュレート

csv ファイルを用いた Node.judge のシミュレートは pisat.test.core.util 内の **simulate_judge_from** 関数を使うと便利です．
ただし制限があり，**別途 Node.judge に相当する関数を定義** する必要があります．
例えば，

```python
import pisat.config.dname as dname
from pisat.core.nav import Node

class TestNode(Node):

    def judge(self, data):
        altitude = data[dname.ALTITUDE_SEALEVEL]

        if altitude < 10:
            return True
        else:
            return False
```

という Node があった場合，

```python

def judge_testnode(data):
    altitude = data[dname.ALTITUDE_SEALEVEL]

    if altitude < 10:
        return True
    else:
        return False
```

のような関数を定義する必要があるということです．
この関数を用いると以下のように過去のデータから関数をシミュレート出来ます．

```python
from pisat.test.core.util import simulate_judge_from

def judge_testnode(data):
    altitude = data[dname.ALTITUDE_SEALEVEL]

    if altitude < 10:
        return True
    else:
        return False

if __name__ == "__main__":
    csv_file = "xxxxxxxx.csv"

    # フラグが検知されたデータのインデックス (行数) を返す
    # 第1引数 --> Node.judge に相当する関数
    # 第2引数 --> 自身を指すフラグ値
    # 第3引数 --> csv ファイルのパス
    # 第4引数 --> csv ファイルのデータ名 (オプション)
    index_flag_detected = simulate_judge_from(judge_testnode, False, csv_file)
```

*simulate_judge_from* 関数の第4引数はオプションですが，CSV ファイルの1行目にデータ名の記載がない場合や
Node.judge に相当する関数内で使用するデータ名と CSV ファイル1行目に記載されているデータ名が合わない場合などは
必ず指定する必要があります．

## まとめ

ここでは開発におけるテストとその際に必要となる依存関係の解決などの方法を述べました．
特にテストを行う前に can09 を最新にしておくために，

```
$ python local.py (Windows)
$ python _local.py (Mac or Linux)
```

を実行しておく癖を付けましょう．

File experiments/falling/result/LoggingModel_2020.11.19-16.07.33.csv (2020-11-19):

sensor_controller-acc_x | sensor_controller-acc_y | sensor_controller-acc_z | sensor_controller-altitude | sensor_controller-altitude_gps | sensor_controller-gra_x | sensor_controller-gra_y | sensor_controller-gra_z | sensor_controller-heading | sensor_controller-latitude | sensor_controller-longitude | sensor_controller-pitch | sensor_controller-press | sensor_controller-roll | sensor_controller-temp
0.0 | 0.0 | 0.0 | 133.94724445654907 |  | 0.0 | 0.0 | 0.0 | 0.0 |  |  | 0.0 | 997.889940032959 | 0.0 | 26.05230779578915
0.0 | 0.0 | 0.0 | 133.94724445654907 |  | 0.0 | 0.0 | 0.0 | 0.0 |  |  | 0.0 | 997.889940032959 | 0.0 | 26.05230779578915
0.0 | 0.0 | 0.0 | 133.94724445654907 |  | 0.0 | 0.0 | 0.0 | 0.0 |  |  | 0.0 | 997.889940032959 | 0.0 | 26.05230779578915
0.0 | 0.0 | 0.0 | 133.94724445654907 |  | 0.0 | 0.0 | 0.0 | 0.0 |  |  | 0.0 | 997.889940032959 | 0.0 | 26.05230779578915
0.0 | 0.0 | 0.0 | 133.94724445654907 |  | 0.0 | 0.0 | 0.0 | 0.0 |  |  | 0.0 | 997.889940032959 | 0.0 | 26.05230779578915
0.0 | 0.0 | 0.0 | 133.94724445654907 |  | 0.0 | 0.0 | 0.0 | 0.0 |  |  | 0.0 | 997.889940032959 | 0.0 | 26.05230779578915
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

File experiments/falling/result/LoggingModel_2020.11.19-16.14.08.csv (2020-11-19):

sensor_controller-acc_x | sensor_controller-acc_y | sensor_controller-acc_z | sensor_controller-altitude | sensor_controller-altitude_gps | sensor_controller-gra_x | sensor_controller-gra_y | sensor_controller-gra_z | sensor_controller-heading | sensor_controller-latitude | sensor_controller-longitude | sensor_controller-pitch | sensor_controller-press | sensor_controller-roll | sensor_controller-temp
-0.08 | 0.0 | -0.04 | 133.87093601332649 |  | -0.01 | 3.21 | -9.26 | 180.375 |  |  | 0.0 | 997.9107788085937 | 160.875 | 26.291812191809644
-0.08 | 0.0 | -0.04 | 133.87093601332649 |  | -0.01 | 3.21 | -9.26 | 180.375 |  |  | 0.0 | 997.9107788085937 | 160.875 | 26.291812191809644
-0.08 | 0.0 | -0.04 | 133.87093601332649 |  | -0.01 | 3.21 | -9.26 | 180.375 |  |  | 0.0 | 997.9107788085937 | 160.875 | 26.291812191809644
-0.08 | 0.0 | -0.04 | 133.87093601332649 |  | -0.01 | 3.21 | -9.26 | 180.375 |  |  | 0.0 | 997.9107788085937 | 160.875 | 26.291812191809644
-0.08 | 0.0 | -0.04 | 133.87093601332649 |  | -0.01 | 3.21 | -9.26 | 180.375 |  |  | 0.0 | 997.9107788085937 | 160.875 | 26.291812191809644
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

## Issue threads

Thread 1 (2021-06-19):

リポジトリサイトのホームページ

jjj999, 2021-06-19:
**Is your feature request related to a problem? Please describe.**

ホームページがダサい（というか何もない）．

**Describe the solution you'd like**

以下の情報を記載する：

- サイトの概要
- アプリケーションのインストール方法
- 開発者向けの案内
- 問い合わせ先の案内

**Describe alternatives you've considered**

**Additional context**

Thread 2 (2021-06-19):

README の修正

jjj999, 2021-06-19:
**Is your feature request related to a problem? Please describe.**

- README の情報が薄い
- リポジトリサイトへの案内がない

**Describe the solution you'd like**

- 基本的な情報は全てリポジトリサイトでまとめられているので，訪問者をリポジトリサイトに誘導するようにする
- 開発者向けの案内については別途記載しておく

**Describe alternatives you've considered**

**Additional context**

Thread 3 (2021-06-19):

リポジトリサイトの *Project* を記載する

jjj999, 2021-06-19:
**Is your feature request related to a problem? Please describe.**

現在白紙状態（https://from-the-earth.github.io/canbeta/project/）．

**Describe the solution you'd like**

- プロジェクトの概要を記載する
- ミッションの概要を記載する
- 大まかなプロジェクトの計画・日程について記載する

**Describe alternatives you've considered**

**Additional context**

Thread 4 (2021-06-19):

リポジトリサイトの *Development* を記載する

jjj999, 2021-06-19:
**Is your feature request related to a problem? Please describe.**

現状白紙状態（https://from-the-earth.github.io/canbeta/dev/）．

**Describe the solution you'd like**

- `canbeta` の開発の概要を記載する
- チーム開発のワークフローを記載する
- コントリビュート方法について記載する
- ハードウェアについて記載する
- リポジトリのディレクトリ構造について記載する
- 依存関係について記載する
- 開発環境およびその設定について記載する
- 開発中の Python パッケージについて記載する
    - ミッションのフローチャートを記載する
    - ノードの種類について記載する
    - アプリケーションの設定について記載する

**Describe alternatives you've considered**

**Additional context**

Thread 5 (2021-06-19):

アプリケーションの設定管理のために gileum を導入する

jjj999, 2021-06-19:
**Is your feature request related to a problem? Please describe.**

現在アプリケーションの設定は，`canbeta.setting` モジュールによって定義されている．しかし，この状態ではアプリケーションのインストール後の設定の変更が出来ない状態になっており，これは実行時に大きな支障をもたらしている．

**Describe the solution you'd like**

上記問題を解決するために，[gileum](https://github.com/jjj999/gileum) を導入する．gileum の特徴は設定ファイルを Python スクリプトとして記述出来る点であり，さらに内部で [pydantic](https://pydantic-docs.helpmanual.io/) を使用することにより型検査などの設定値のバリデーションを行うことが出来る．この gileum を使用することで，容易にアプリケーションに設定ファイルの機構を設けるとことが出来ると考えられる．

**Describe alternatives you've considered**

**Additional context**

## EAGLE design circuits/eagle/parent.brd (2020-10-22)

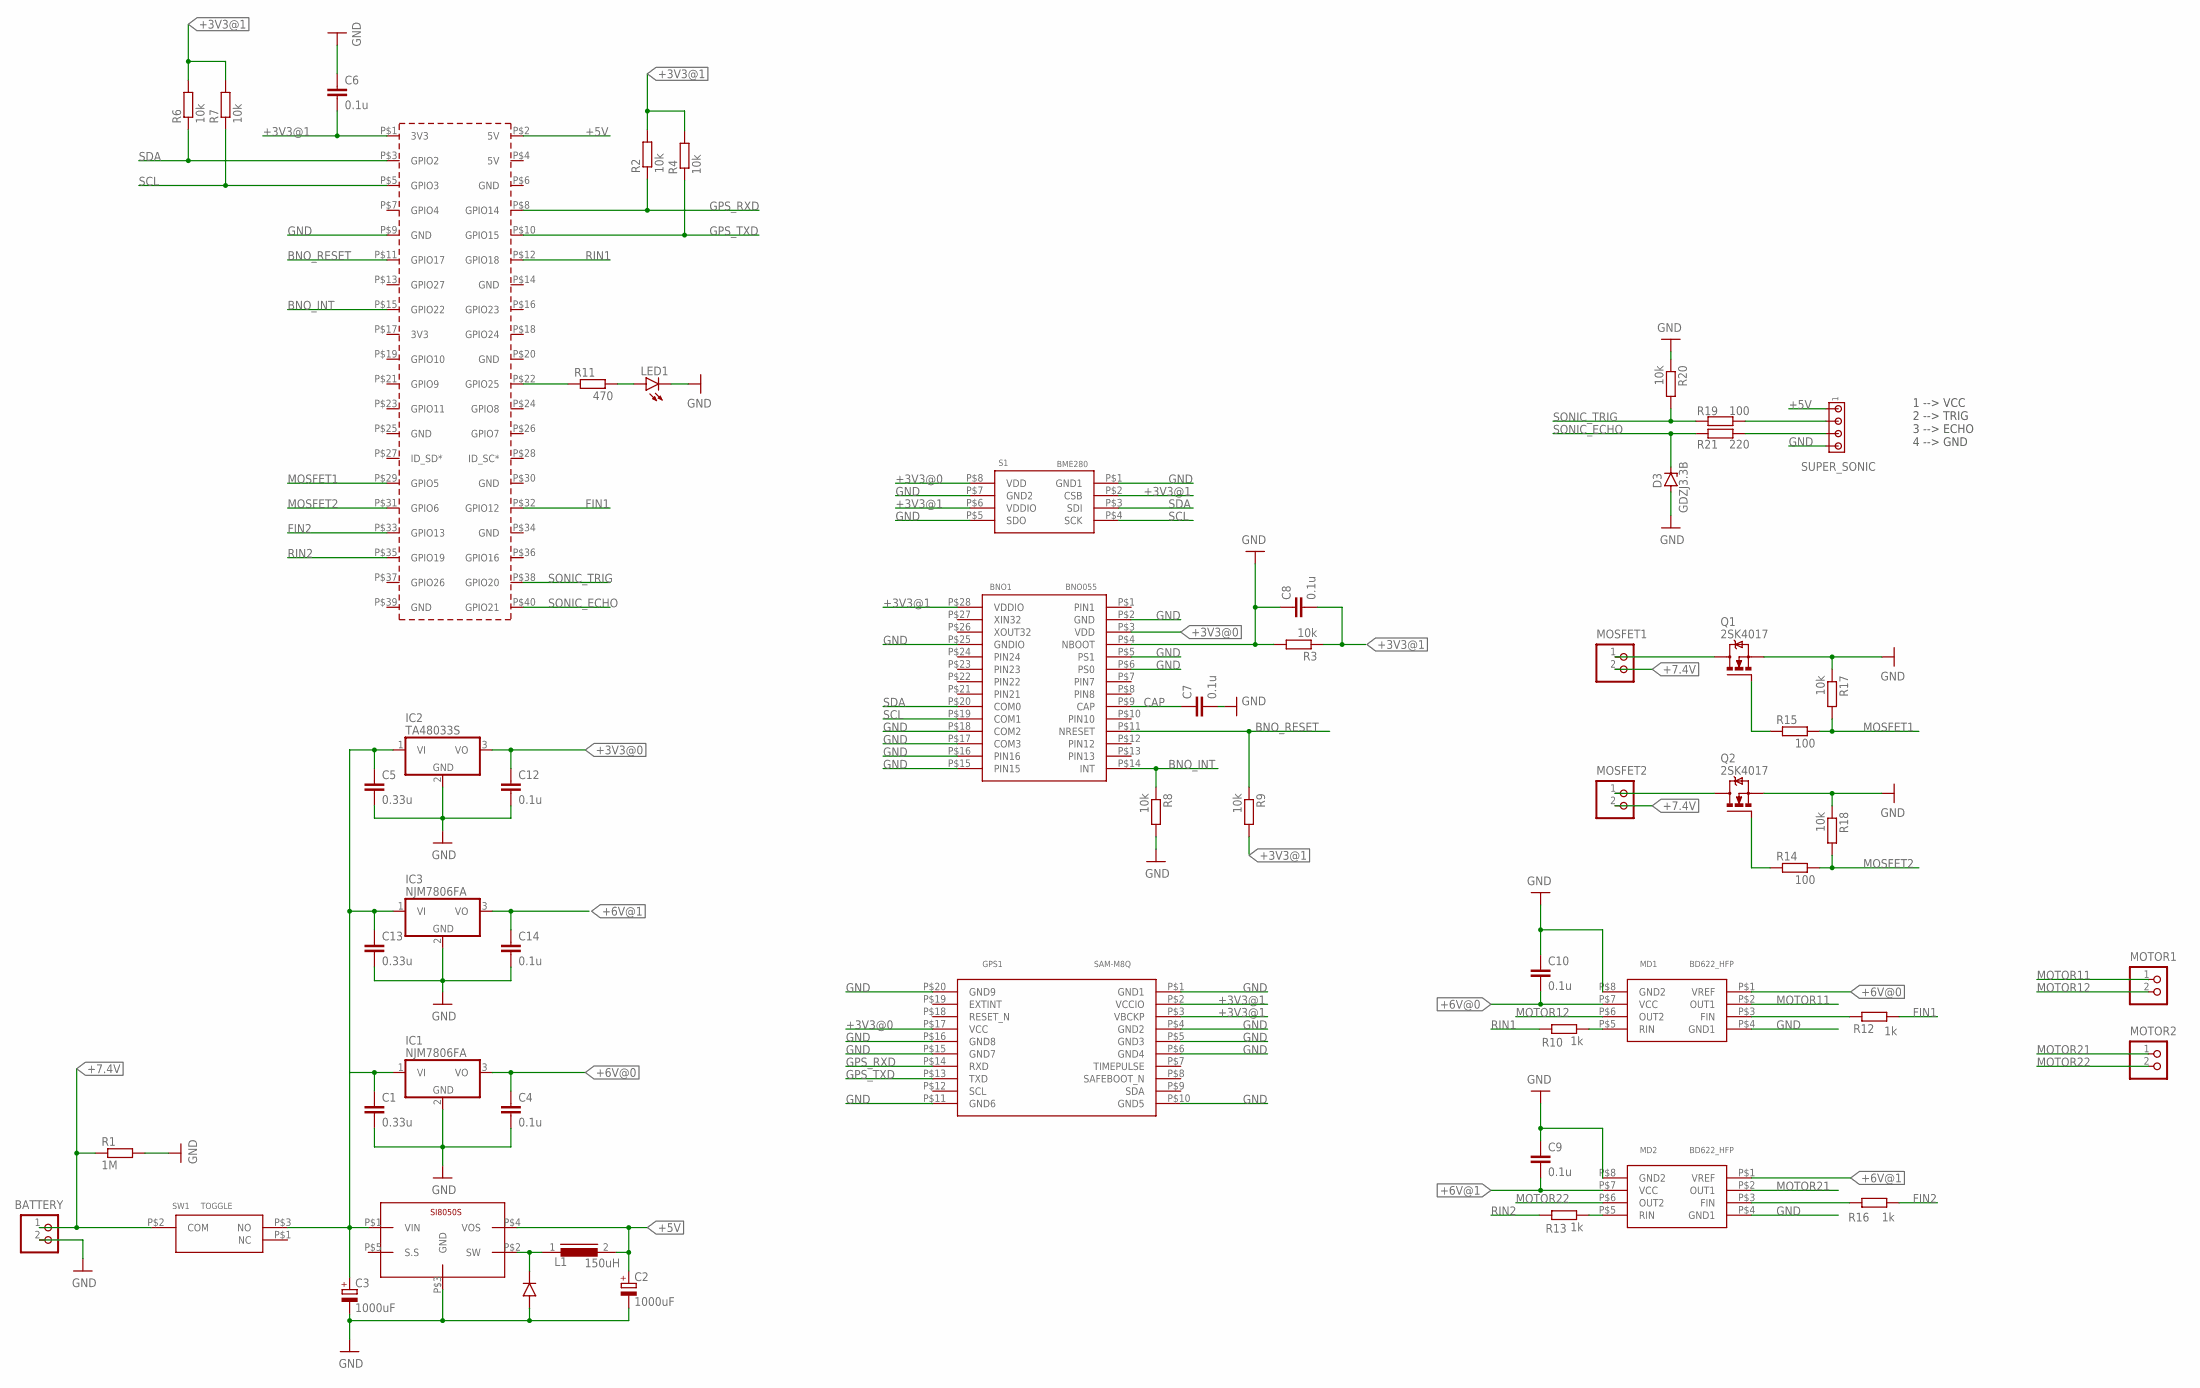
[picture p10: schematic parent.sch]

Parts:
BATTERY: B2P-VH
BNO1: BNO055
C1, C5, C13: 0.33u; C5B3
C2, C3: 1000uF; E5-10,5
C4, C12, C14: 0.1u; C5B3
C6, C7, C8, C9, C10: 0.1u; C1608
D3: GDZJ3.3B; DO35Z10
DIODE_1.1: DIODE_1.5
GPS1: SAM-M8Q
IC1, IC3: NJM7806FA; TO220V
IC2: TA48033S; TO220V
L1: 150uH; SFT830D
LED1: LED5MM
MD1, MD2: BD622_HFP; BD62**_HRP7
MOSFET1, MOSFET2: B2P-VH
MOTOR1, MOTOR2: B2P-VH
PCB1: RPI3RPI3; RPI3
Q1, Q2: 2SK4017; TO220BV
R1: 1M; R2012
R2, R3, R4, R6, R7, R8, R9, R17, R18, R20: 10k; R2012
R10, R12, R13, R16: 1k; R2012
R11: 470; 0207/10
R14, R15, R19: 100; 0207/10
R21: 220; 0207/10
S1: BME280
SI8050S1: SI8050S
SUPER_SONIC: MTA04-100; 10X04MTA
SW1: TOGGLE; TOGGLE_1MS1-T1-B1-M2-Q-N-S

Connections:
+3V3@0: BNO1.P$3 (VDD), C12.1, GPS1.P$17 (VCC), IC2.3 (VO), S1.P$8 (VDD)
+3V3@1: BNO1.P$28 (VDDIO), C6.2, C8.2, GPS1.P$2 (VCCIO), GPS1.P$3 (VBCKP), PCB1.P$1 (3V3), R2.2, R3.1, R4.2, R6.2, R7.2, R9.2, S1.P$2 (CSB), S1.P$6 (VDDIO)
+5V: C2.+, L1.2, PCB1.P$2 (5V), SI8050S1.P$4 (VOS), SUPER_SONIC.1
+6V@0: C4.1, C10.2, IC1.3 (VO), MD1.P$1 (VREF), MD1.P$7 (VCC)
+6V@1: C9.2, C14.1, IC3.3 (VO), MD2.P$1 (VREF), MD2.P$7 (VCC)
+7.4V: BATTERY.1, MOSFET1.2, MOSFET2.2, R1.1, SW1.P$2 (COM)
BNO_INT: BNO1.P$14 (INT), PCB1.P$15 (GPIO22), R8.1
BNO_RESET: BNO1.P$11 (NRESET), PCB1.P$11 (GPIO17), R9.1
CAP: BNO1.P$9 (CAP), C7.1
FIN1: PCB1.P$32 (GPIO12), R12.2
FIN2: PCB1.P$33 (GPIO13), R16.2
GND: BATTERY.2, BNO1.P$2 (GND), BNO1.P$4 (NBOOT), BNO1.P$5 (PS1), BNO1.P$6 (PS0), BNO1.P$15 (PIN15), BNO1.P$16 (PIN16), BNO1.P$17 (COM3), BNO1.P$18 (COM2), BNO1.P$25 (GNDIO), C1.2, C2.-, C3.-, C4.2, C5.2, C6.1, C7.2, C8.1, C9.1, C10.1, C12.2, D3.A, DIODE_1.1.P$1 (ANODE), GPS1.P$1 (GND1), GPS1.P$4 (GND2), GPS1.P$5 (GND3), GPS1.P$6 (GND4), GPS1.P$10 (GND5), GPS1.P$11 (GND6), GPS1.P$15 (GND7), GPS1.P$16 (GND8), GPS1.P$20 (GND9), IC1.2 (GND), IC2.2 (GND), LED1.K (C), MD1.P$4 (GND1), MD1.P$8 (GND2), MD2.P$4 (GND1), MD2.P$8 (GND2), PCB1.P$9 (GND), Q1.S, Q2.S, R1.2, R3.2, R8.2, R17.1, R18.1, R20.1, S1.P$1 (GND1), S1.P$5 (SDO), S1.P$7 (GND2), SI8050S1.P$3 (GND), SUPER_SONIC.4
GPS_RXD: GPS1.P$14 (RXD), PCB1.P$8 (GPIO14), R2.1
GPS_TXD: GPS1.P$13 (TXD), PCB1.P$10 (GPIO15), R4.1
MOSFET1: PCB1.P$29 (GPIO5), R15.2, R17.2
MOSFET2: PCB1.P$31 (GPIO6), R14.2, R18.2
MOTOR11: MD1.P$2 (OUT1), MOTOR1.1
MOTOR12: MD1.P$6 (OUT2), MOTOR1.2
MOTOR21: MD2.P$2 (OUT1), MOTOR2.1
MOTOR22: MD2.P$6 (OUT2), MOTOR2.2
unnamed: DIODE_1.1.P$2 (CATHODE), L1.1, SI8050S1.P$2 (SW)
unnamed: PCB1.P$22 (GPIO25), R11.1
unnamed: C1.1, C3.+, C5.1, C13.1, IC1.1 (VI), IC2.1 (VI), IC3.1 (VI), SI8050S1.P$1 (VIN), SW1.P$3 (NO)
unnamed: LED1.A, R11.2
unnamed: MOSFET1.1, Q1.D
unnamed: MD1.P$3 (FIN), R12.1
unnamed: MOSFET2.1, Q2.D
unnamed: MD1.P$5 (RIN), R10.2
unnamed: Q1.G, R15.1
unnamed: Q2.G, R14.1
unnamed: MD2.P$3 (FIN), R16.1
unnamed: C13.2, C14.2, IC3.2 (GND)
unnamed: MD2.P$5 (RIN), R13.2
unnamed: R19.2, SUPER_SONIC.2
unnamed: R21.2, SUPER_SONIC.3
RIN1: PCB1.P$12 (GPIO18), R10.1
RIN2: PCB1.P$35 (GPIO19), R13.1
SCL: BNO1.P$19 (COM1), PCB1.P$5 (GPIO3), R7.1, S1.P$4 (SCK)
SDA: BNO1.P$20 (COM0), PCB1.P$3 (GPIO2), R6.1, S1.P$3 (SDI)
SONIC_ECHO: D3.C, PCB1.P$40 (GPIO21), R21.1
SONIC_TRIG: PCB1.P$38 (GPIO20), R19.1, R20.2

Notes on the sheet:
1 --> VCC 2 --> TRIG 3 --> ECHO 4 --> GND

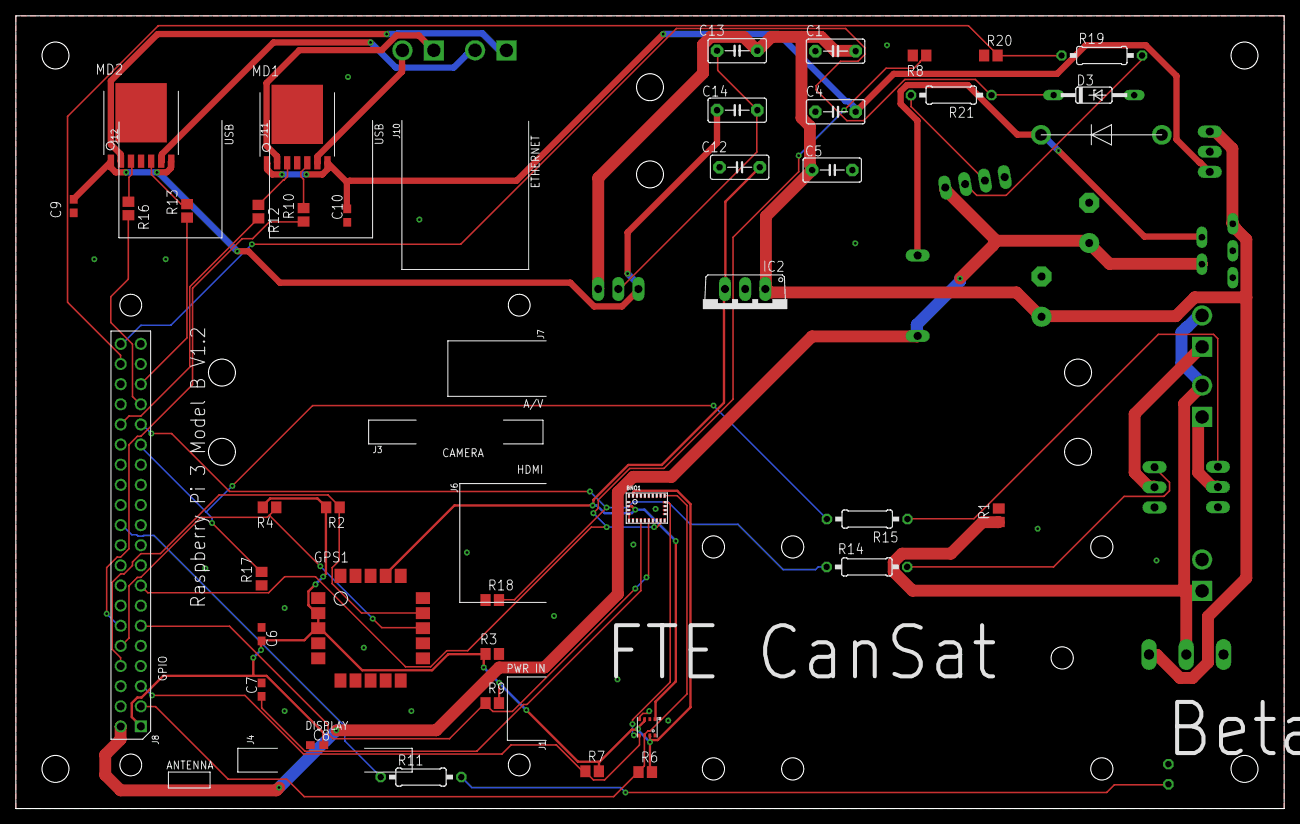
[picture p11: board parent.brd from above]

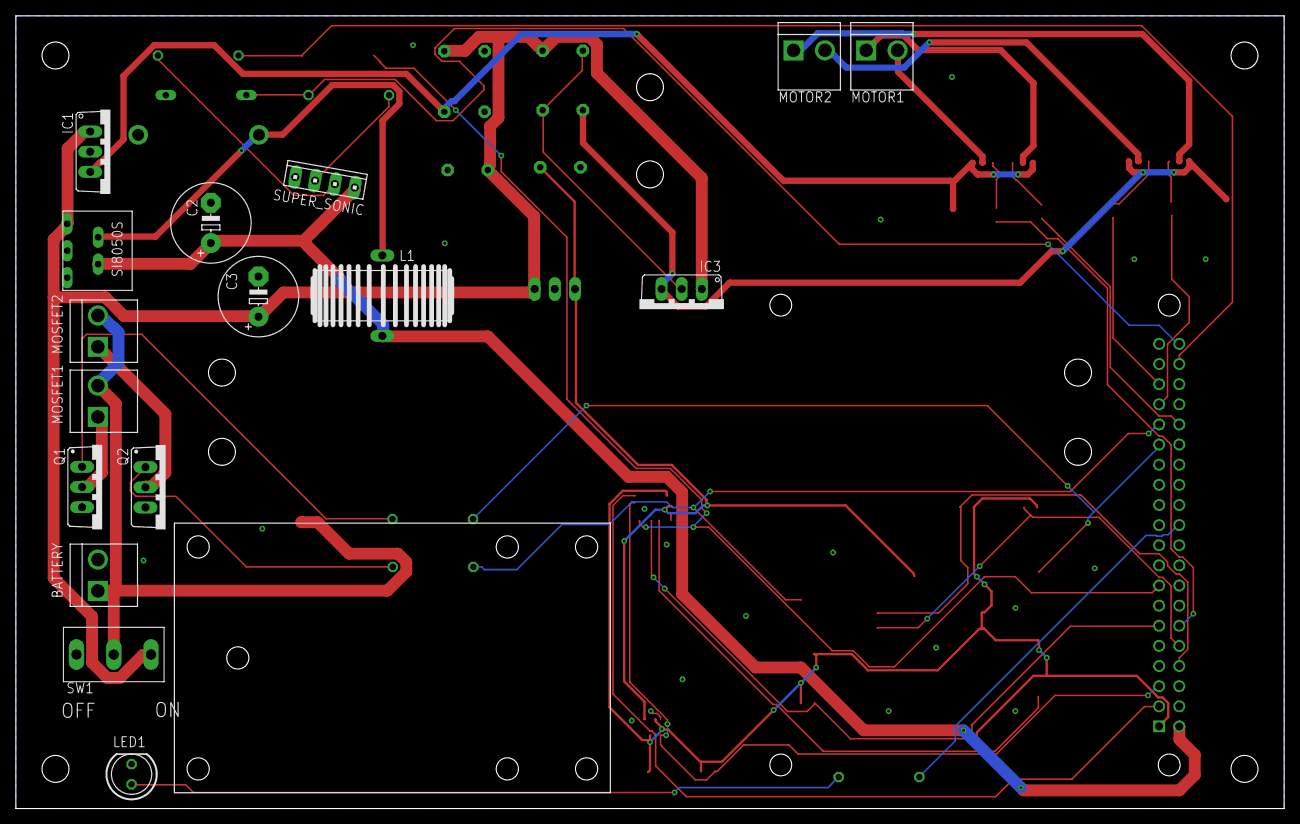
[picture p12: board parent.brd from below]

Board: 2 copper layers, 160.0 x 100.0 mm, 56 parts (16 on the bottom side), 41 nets.

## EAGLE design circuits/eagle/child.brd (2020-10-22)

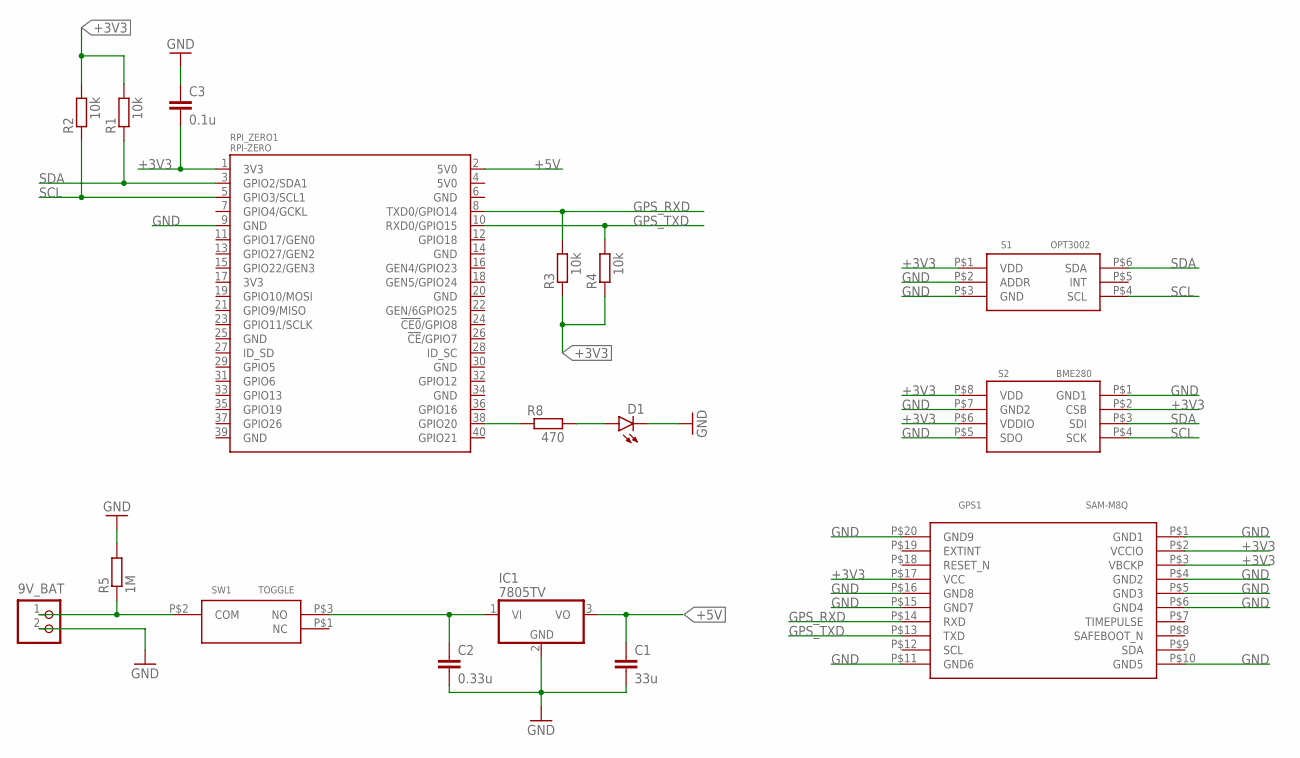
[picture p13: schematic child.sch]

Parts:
9V_BAT: B2P-VH
C1: 33u; C5B3
C2: 0.33u; C5B3
C3: 0.1u; C1206
D1: SFH482
GPS1: SAM-M8Q
IC1: 7805TV; TO220V
R1, R2, R3, R4: 10k; R1206
R5: 1M; 0207/10
R8: 470; 0207/10
RPI_ZERO1: RPI-ZERO; RASP_PI_ZERO_BOARD_FULL
S1: OPT3002
S2: BME280
SW1: TOGGLE; TOGGLE_1MS1-T1-B1-M2-Q-N-S

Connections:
+3V3: C3.2, GPS1.P$2 (VCCIO), GPS1.P$3 (VBCKP), GPS1.P$17 (VCC), R1.2, R2.2, R3.1, R4.1, RPI_ZERO1.1 (3V3), S1.P$1 (VDD), S2.P$2 (CSB), S2.P$6 (VDDIO), S2.P$8 (VDD)
+5V: C1.1, IC1.3 (VO), RPI_ZERO1.2 (5V0)
GND: 9V_BAT.2, C1.2, C2.2, C3.1, D1.K (C), GPS1.P$1 (GND1), GPS1.P$4 (GND2), GPS1.P$5 (GND3), GPS1.P$6 (GND4), GPS1.P$10 (GND5), GPS1.P$11 (GND6), GPS1.P$15 (GND7), GPS1.P$16 (GND8), GPS1.P$20 (GND9), IC1.2 (GND), R5.2, RPI_ZERO1.9 (GND), S1.P$2 (ADDR), S1.P$3 (GND), S2.P$1 (GND1), S2.P$5 (SDO), S2.P$7 (GND2)
GPS_RXD: GPS1.P$14 (RXD), R3.2, RPI_ZERO1.8 (TXD0/GPIO14)
GPS_TXD: GPS1.P$13 (TXD), R4.2, RPI_ZERO1.10 (RXD0/GPIO15)
unnamed: R8.1, RPI_ZERO1.38 (GPIO20)
unnamed: D1.A, R8.2
SCL: R2.1, RPI_ZERO1.5 (GPIO3/SCL1), S1.P$4 (SCL), S2.P$4 (SCK)
SDA: R1.1, RPI_ZERO1.3 (GPIO2/SDA1), S1.P$6 (SDA), S2.P$3 (SDI)
V+: 9V_BAT.1, R5.1, SW1.P$2 (COM)
VIN: C2.1, IC1.1 (VI), SW1.P$3 (NO)

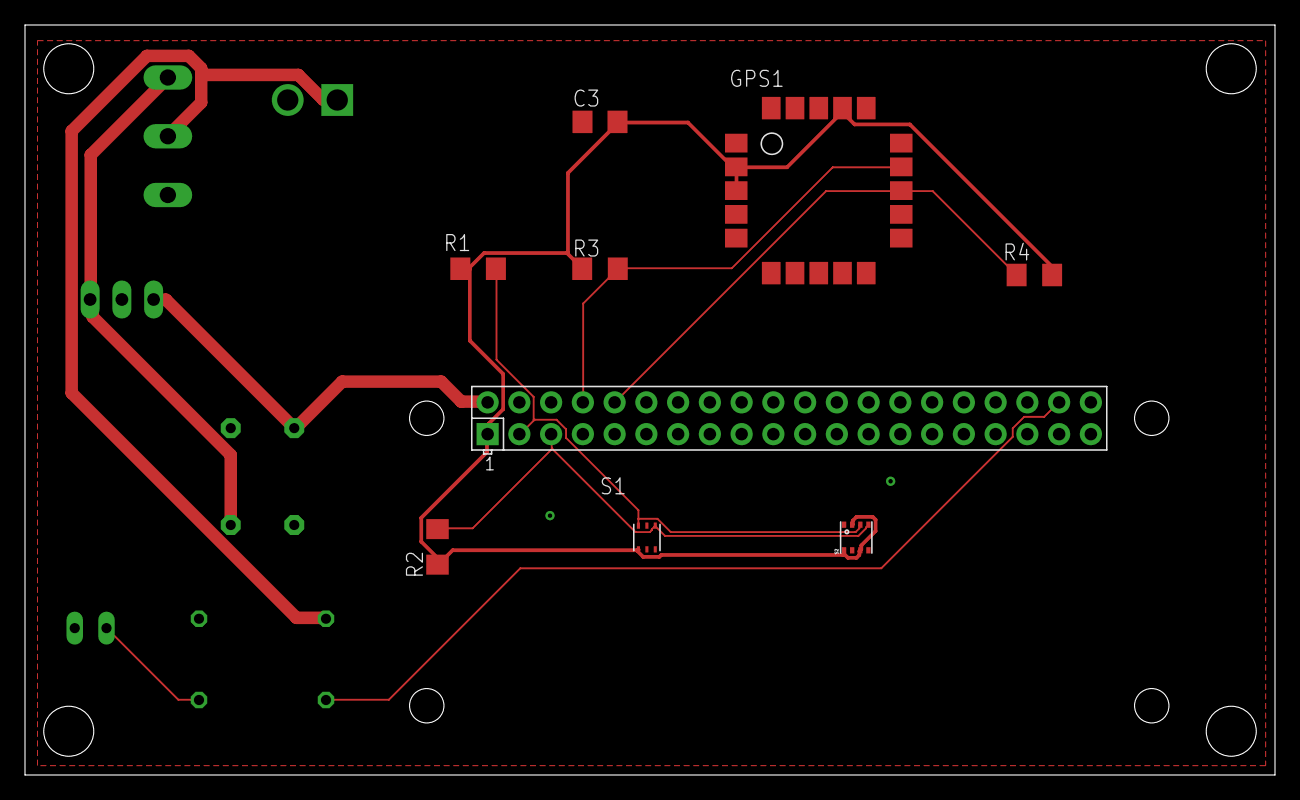
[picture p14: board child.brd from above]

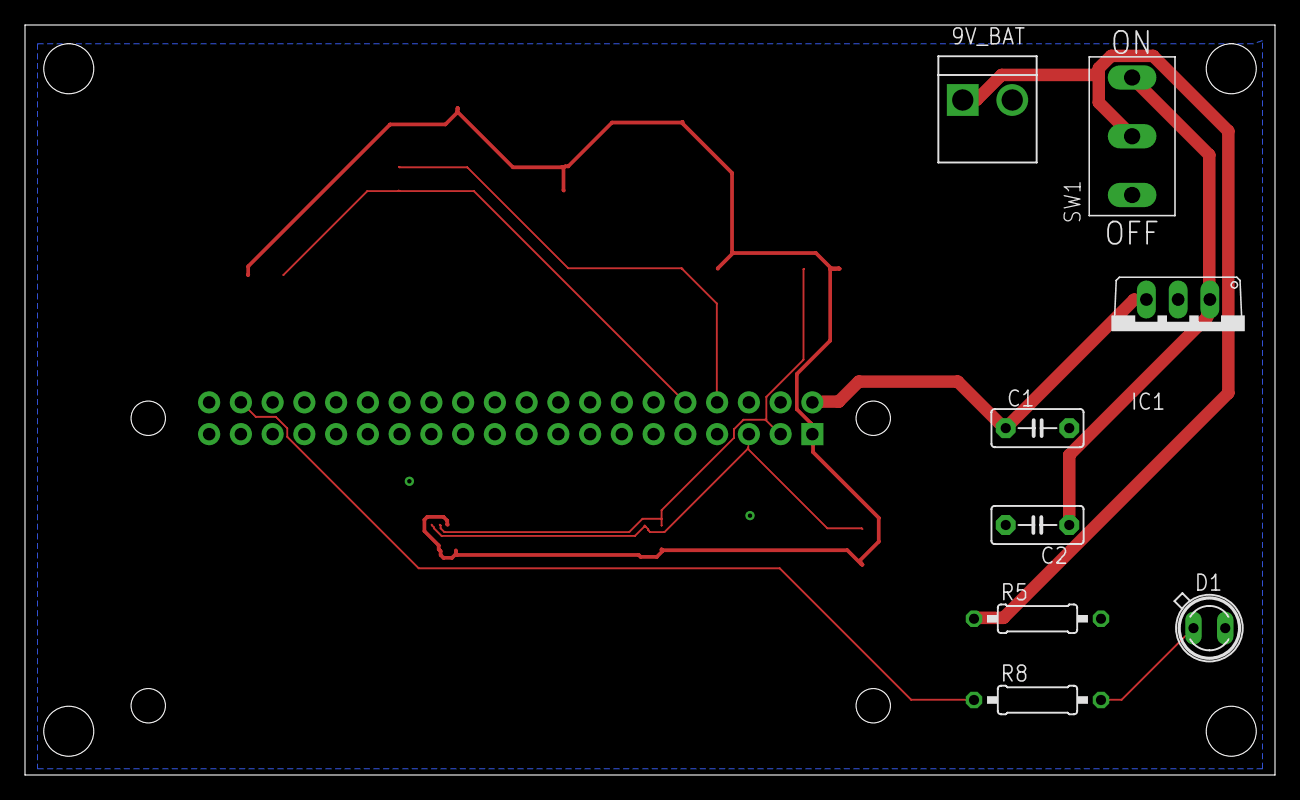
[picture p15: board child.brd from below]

Board: 2 copper layers, 100.0 x 60.0 mm, 17 parts (8 on the bottom side), 11 nets.

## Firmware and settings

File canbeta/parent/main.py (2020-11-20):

import pigpio
from pisat.actuator import BD62xx, TwoWheels
from pisat.comm.transceiver import Im920, SocketTransceiver
from pisat.core.cansat import CanSat
from pisat.core.nav import Context
from pisat.core.manager import ComponentManager
from pisat.core.logger import (
    DataLogger, LogQueue, SystemLogger
)
from pisat.handler import (
    PigpioI2CHandler, PyserialSerialHandler,
    PigpioDigitalInputHandler, PigpioDigitalOutputHandler,
    PigpioPWMHandler
)
from pisat.sensor import Bno055, Bme280, SamM8Q, HcSr04

from can09.parent.model import LoggingModel
from can09.parent.nodes import *
from can09.parent.setting import *


def run_parent():

    # device setting
    pi = pigpio.pi()
    
    handler_bno055 = PigpioI2CHandler(pi, I2C_ADDRESS_BNO055)
    handler_bme280 = PigpioI2CHandler(pi, I2C_ADDRESS_BME280)
    handler_gps = PyserialSerialHandler(SERIAL_PORT_GPS, baudrate=BAUDRATE_GPS)
    handler_im920 = PyserialSerialHandler(SERIAL_PORT_IM920, baudrate=BAUDRATE_IM920)
    
    handler_motor_L_fin = PigpioPWMHandler(pi, GPIO_MOTOR_L_FIN, freq=MOTOR_PWM_FREQ)
    handler_motor_L_rin = PigpioPWMHandler(pi, GPIO_MOTOR_L_RIN, freq=MOTOR_PWM_FREQ)
    handler_motor_R_fin = PigpioPWMHandler(pi, GPIO_MOTOR_R_FIN, freq=MOTOR_PWM_FREQ)
    handler_motor_R_rin = PigpioPWMHandler(pi, GPIO_MOTOR_R_RIN, freq=MOTOR_PWM_FREQ)
    handler_mosfet_para = PigpioDigitalOutputHandler(pi, GPIO_MOSFET_PARA, name=NAME_MOSFET_PARA)
    handler_mosfet_child = PigpioDigitalOutputHandler(pi, GPIO_MOSFET_CHILD, name=NAME_MOSFET_CHILD)
    handler_sonic_trig = PigpioDigitalOutputHandler(pi, GPIO_SONIC_TRIG)
    handler_sonic_echo = PigpioDigitalInputHandler(pi, GPIO_SONIC_ECHO)
    handler_led = PigpioDigitalOutputHandler(pi, GPIO_LED, name=NAME_LED)

    # actuator
    motor_L = BD62xx(handler_motor_L_fin, handler_motor_L_rin, name=NAME_MOTOR_L)
    motor_R = BD62xx(handler_motor_R_fin, handler_motor_R_rin, name=NAME_MOTOR_R)
    wheels = TwoWheels(motor_L, motor_R, name=NAME_WHEELS)

    # transceiver
    im920 = Im920(handler_im920, name=NAME_IM920)
    im920.clear_buf()
    socket_transceiver = SocketTransceiver(im920, certain=True, name=NAME_SOCKET_TRANSCEIVER)

    # sensor
    bno055 = Bno055(handler_bno055, name=NAME_BNO055)
    bno055.change_operation_mode(Bno055.OperationMode.NDOF)
    bno055.remap_axis(Bno055.Axis.Y, Bno055.Axis.X, Bno055.Axis.Z)
    bno055.remap_sign(y=Bno055.AxisSign.NEGATIVE)
    bme280 = Bme280(handler_bme280, name=NAME_BME280)
    gps = SamM8Q(handler_gps, name=NAME_GPS)
    sonic = HcSr04(handler_sonic_echo, handler_sonic_trig, name=NAME_SUPERSONIC)
    
    que = LogQueue(LoggingModel, maxlen=10000, name=NAME_LOGQUEUE)
    dlogger = DataLogger(que, bno055, bme280, gps, sonic, name=NAME_DATA_LOGGER)

    slogger = SystemLogger(name=NAME_SYSTEM_LOGGER)
    slogger.setFileHandler()

    # register callable components in Nodes
    manager = ComponentManager(motor_L, motor_R, wheels, im920, socket_transceiver, 
                               handler_mosfet_para, handler_mosfet_child, handler_led, dlogger, slogger, 
                               recursive=True, name=NAME_MANAGER)

    # context setting
    context = Context({
                        MissionStandbyNode: {True: FallingNode,         False: MissionStandbyNode},
                        FallingNode:        {True: ParaSeparateNode,    False: FallingNode},
                        ParaSeparateNode:   {True: FirstRunningNode,    False: ParaSeparateNode},
                        FirstRunningNode:   {True: ChildSeparateNode,   False: FirstRunningNode},
                        ChildSeparateNode:  {True: SencondRunningNode,  False: ChildSeparateNode},
                        SencondRunningNode: {True: GoalSearchNode,      False: SencondRunningNode},
                        GoalSearchNode:     {True: GoalDetectNode,      False: GoalSearchNode},
                        GoalDetectNode:     {True: None,                False: GoalDetectNode}
                    },
                    start=MissionStandbyNode)

    # build a cansat
    cansat = CanSat(context, manager, dlogger=dlogger, slogger=slogger)
    cansat.run()


if __name__ == "__main__":
    run_parent()

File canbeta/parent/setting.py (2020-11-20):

# component name
NAME_MOTOR_L = "motor_l"
NAME_MOTOR_R = "motor_r"
NAME_WHEELS = "wheels"

NAME_BME280 = "bme280"
NAME_BNO055 = "bno055"
NAME_GPS = "gps"
NAME_IM920 = "im920"
NAME_SOCKET_TRANSCEIVER = "socket_transceiver"
NAME_SUPERSONIC = "supersonic"

NAME_MOSFET_PARA = "mosfet_para"
NAME_MOSFET_CHILD = "mosfet_child"

NAME_SENSOR_CONTROLLER = "sensor_controller"
NAME_LOGQUEUE = "logqueue"
NAME_DATA_LOGGER = "dlogger"
NAME_SYSTEM_LOGGER = "slogger"
NAME_MANAGER = "manager"
NAME_LED = "led"

# device setting
# TODO Check motors' pins
GPIO_MOTOR_L_FIN = 12
GPIO_MOTOR_L_RIN = 18
GPIO_MOTOR_R_FIN = 13
GPIO_MOTOR_R_RIN = 19
GPIO_MOSFET_PARA = 5
GPIO_MOSFET_CHILD = 6
GPIO_SONIC_TRIG = 20
GPIO_SONIC_ECHO = 21
GPIO_LED = 25

MOTOR_PWM_FREQ = 40_0000

I2C_ADDRESS_BNO055 = 0x28
I2C_ADDRESS_BME280 = 0x76
I2C_ADDRESS_OPT3002 = 0x68
SERIAL_PORT_GPS = "/dev/serial0"
SERIAL_PORT_IM920 = "/dev/ttyUSB0"

BAUDRATE_IM920 = 19200
BAUDRATE_GPS = 9600

# TODO Set parameters below
# Threshold setting
THRESHOLD_CAMERA_DETECTION = 1.

# PID control setting
KP = 1.
KI = 1.
KD = 1.
MAX_DUTY = 100.
MIN_DUTY = 0.
SSE_RATIO = 0.1
THRESHOLD_I_CTRLR = 10
DUTY_BASE = 50.
SAMPLE_TIME = 1.

# Longitude and Latitude
POSITION_GOAL = (0., 0.)
POSITION_CHILD = (0., 0.)

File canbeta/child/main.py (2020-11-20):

import pigpio

from pisat.comm.transceiver import Im920, SocketTransceiver
from pisat.core.cansat import CanSat
from pisat.core.nav import Context
from pisat.core.manager import ComponentManager
from pisat.core.logger import (
    DataLogger, LogQueue, SystemLogger
)
from pisat.handler import (
    PigpioI2CHandler, PyserialSerialHandler, PigpioDigitalOutputHandler
)
from pisat.sensor import Bme280, Opt3002, SamM8Q

from can09.child.model import ChildLoggingModel
from can09.child.nodes import *
from can09.child.setting import * 


def run_child():
    pi = pigpio.pi()
    
    # handlers
    handler_bme280 = PigpioI2CHandler(pi, I2C_ADDRESS_BME280)
    handler_opt3002 = PigpioI2CHandler(pi, I2C_ADDRESS_OPT3002)
    handler_gps = PyserialSerialHandler(SERIAL_PORT_GPS, BAUDRATE_GPS)
    handler_im920 = PyserialSerialHandler(SERIAL_PORT_IM920, BAUDRATE_IM920)
    handler_led = PigpioDigitalOutputHandler(pi, GPIO_LED, name=NAME_LED)
    
    # sensors
    bme280 = Bme280(handler_bme280, name=NAME_BME280)
    opt3002 = Opt3002(handler_opt3002, name=NAME_OPT3002)
    gps = SamM8Q(handler_gps, name=NAME_GPS)
    
    # transceiver
    im920 = Im920(handler_im920, name=NAME_IM920)
    socket_transceiver = SocketTransceiver(im920, certain=True, name=NAME_SOCKET_TRANSCEIVER)
    
    # logger
    que = LogQueue(ChildLoggingModel, maxlen=5000, name=NAME_LOGQUEUE)
    dlogger = DataLogger(que, bme280, opt3002, gps, name=NAME_DATA_LOGGER)
    
    slogger = SystemLogger(name=NAME_SYSTEM_LOGGER)
    slogger.setFileHandler()
    
    manager = ComponentManager(handler_led, im920, socket_transceiver, dlogger,
                               recursive=True, name=NAME_MANAGER)
    
    context = Context({
                        MissionStandbyNode: {True: ChildServerNode, False: MissionStandbyNode},
                        ChildServerNode:    {True: None,            False: ChildServerNode}
                      },
                      start=MissionStandbyNode)
    
    cansat = CanSat(context, manager, dlogger=dlogger, slogger=slogger)
    cansat.run()


if __name__ == "__main__":
    run_child()

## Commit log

2020-08-29 add analysis of the result of Precursor
    [precursor.csv]
2020-08-29 fix typo
    [precursor.csv]
2020-08-29 add legend and fix the unit of gyro
2020-10-03 fix dependancy of pisat
    [main.py, setting.py]
2020-10-19 set fethandler in main and para
2020-10-22 add datasheets of devices to be used
2020-10-22 add circuit's data
    [2020can_master_v1.brd, 2020can_master_v1.sch, 2020can_master_v2.brd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]
2020-10-23 add files for flowcharts
2020-10-23 added the flow charts
2020-10-23 added flowchart
2020-10-24 add server package for handling wireless commands
2020-10-27 para&fallin flowchart
2020-11-05 put together flowcharts into a single file
2020-11-05 modified all flowcharts
2020-11-12 added sample-timer
2020-11-12 added sample conter
2020-11-19 Added a script for checking current altitude on terminal
2020-11-19 Fixed because of the update of pisat
    [exp_falling.py]
2020-11-19 Removed and fixed some points where bugs may exist
    [limit_sensitivity_method.py]
2020-11-19 Added results of experiment
    [LoggingModel_2020.11.19-16.07.33.csv, LoggingModel_2020.11.19-16.14.08.csv, LoggingModel_2020.11.19-16.25.38.csv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]
2020-11-20 Added device IDs of IM920
2020-11-20 Added SocketTransceiver as a component
2020-11-20 Moved setting of altitude on the ground
2020-11-20 Added result of heating test
    [LoggingModel_2020.11.19-23.47.17.csv]
2021-06-18 Updated the repository.
    [LoggingModel_2020.11.19-16.07.33.csv, LoggingModel_2020.11.19-16.14.08.csv, LoggingModel_2020.11.19-16.25.38.csv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]
2021-06-18 Removed legacy files.
    [2020can_master_v1.brd, 2020can_master_v1.sch, 2020can_master_v2.brd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]
